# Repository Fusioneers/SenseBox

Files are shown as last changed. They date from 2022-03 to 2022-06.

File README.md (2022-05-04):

# Facharbeit

# Tool um gpx anzusehen
https://www.j-berkemeier.de/ShowGPX.html

## Fragestellung
_Kann man anhand von Umgebungsdaten mithilfe einer KI vorhersagen, auf welcher Höhe man sich befindet?
Falls ja, sind diese Vorhersagen genauer als herkömmliche Methoden?_

## Ansatz
Zunächst planen und bauen wir eine Sensorbox, welche diverse Umgebungswerte messen und speichern soll.

Die Sensorbox lassen wir in die Höhe steigen und messen dabei mit einem Seil die tatsächliche Höhe der Box.
Die aufgezeichneten Daten nutzen wir, um eine künstliche Intelligenz durch maschinelles Lernen zu trainieren.

Anschließend wird die Genauigkeit evaluiert und mit denen herkömmlicher Methoden zur Höhenmessung verglichen.

## Anforderungen
### Bauteile
* Microcontroller: Arduino nano / duo
* Sensoren
  * Kombo-Sensor für Luftdruck, Luftfeuchtigkeit & Temperatur
  * Anemometer (Sensor für Windgeschwindigkeit)
* Widerstände
* Kondensatoren
* SD-Karten-Lesegerät
* SD-Karte
* Speichermedium
* Steckbrett
* Steckbrückenkabel (2,54mm)
* LED
* Taster
* Akku
* PLA / Styropor / Schrauben etc.

### Bibliotheken

---
**Fusioneers** ([@Fusioneers](https://github.com/Fusioneers)) 2022

* **Kevin Kretz** ([@theKevinKretz](https://github.com/theKevinKretz))
* **Daniel Meiborg** ([@DanielMeiborg](https://github.com/DanielMeiborg))
* **Paul Maier** ([@C0mput3r5c13nt15t](https://github.com/C0mput3r5c13nt15t))
* **Lukas Pottgiesser** ([@Lukas-Pottgiesser](https://github.com/Lukas-Pottgiesser))

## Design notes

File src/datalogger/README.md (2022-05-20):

# Datalogger

## Besonderheiten bei den Variablen

Das Programm verwendet Variablen, die zur Kompellierung aufgelöst werden. Diese sind vor dem Setup-Teil mit
`#variable wert` gekennzeichent. Der Vorteil dieser Variablen besteht, darin, dass sie keinen Speicherplatz verbrauchen
und es trotzdem ermöglichen das Programm variabel und einfach modifizierbar zu gestallten.

Neben den Variablen findet sich auch folgende Kondition, die auch während der Kompillierung aufgelöst wird. Ist
ECHO_TO_SERIAL auf false gesetzt, wird der eingeschlossene Programmteil also einfach ignoriert und benötigt damit
weder Speicher noch Rechenleistung

~~~ c++
#if ECHO_TO_SERIAL
    ...
#endif //ECHO_TO_SERIAL
  
~~~

## Verwendung von interrupts

Das Programm verwendet einen interrupt für den Hallsensor, welcher im Setup-Teil definiert wird.

Mit der Zeile

~~~ c++
attachInterrupt(digitalPinToInterrupt(hallSensor), hallSensorTriggered, FALLING);
~~~

wird der Arduino darauf angewiesen, jedes mal, wenn der Wert am Port hallSensor von HIGH auf LOW fällt, die
Funktion hallSensorTriggered() aufzurufen, welche dann lastLallSesnorTriggerTime auf einen neuen Wert setzt, der
irgendwann im Loop-Teil engültig in die Log-Datei übertragen wird.

~~~ c++
// Diese Funktion wird immer aufgrufen, wenn die Ausgabe des Hall Sesnor von HIGH zu LOW wechselt (siehe setup)
void hallSensorTriggered() {
  // Falls das Programm am laufen ist
  if (_running) {
    // Setze die Zeit des letzten Aufrufs, auf die aktuelle Zeit
    lastLallSesnorTriggerTime = millis();
  }
}
~~~

Theoretisch ist es möglich, dass der Wert überschrieben wird, bevor er in die Log-Datei übertragen werden konnte. In
der Praxis ist dies allerdings sehr unwahrscheinlich, da dieser etwa 15 bis 20 mal pro Sekunde durchlaufen wird.

## Programmablauf

### Setup-Teil

Zunächst wird im Setup-Teil des Programmes alles initialisier, was im späteren Verlauf verwendet wird.
Darunter sind unter anderem die Log-Files, der BME, sowie weitere Sensoren und auch die LEDs. Hier wird
stets geprüft, ob der entsprechende Prozess erfolgreich verlief, ist dass der Fall, so wird am Ende des
Programmes gewartet, bis der An-/Ausknopf gedrückt wird. Gab es einen Fehler, so wird dieser über die Status LEDs
kommuniziert und zudem am seriellen Monitor ausgegeben.

~~~ c++
void setup(void)
{
  // Kontrolliert ob ein Fehler innerhalb des setup Teils aufgetreten ist
  bool errorOccuredInSetup = false;

  // Initialisiert den seriellen Monitor
  Serial.begin(9600);
  
  // Setzt den Pin-Mode der Status-LEDs auf OUTPUT
  pinMode(redLED, OUTPUT);
  pinMode(yellowLED, OUTPUT);
  pinMode(greenLED, OUTPUT);

  // Setzt den Pin-Mode des An- Ausschalters auf INPUT
  pinMode(onOffButton, INPUT);

  // Setzt den Pin-Mode des Hallsesnors auf INPUT
  pinMode(hallSensor, INPUT);
  
  // Attached die Funktion hallSensorTriggered, zu einem Ändern der Voltage am Port hallSensor von HIGH zu LOW
  attachInterrupt(digitalPinToInterrupt(hallSensor), hallSensorTriggered, FALLING);

  // Die gelbe LED wird für den restlichen Setup-Teil angeschaltet
  digitalWrite(yellowLED, HIGH); 

  Serial.println("Initializing SD card...");
  
  // Setzt den SD-Karten Pin vorsichtshalber bereits auf OUTPUT
  pinMode(10, OUTPUT);

  // Falls die SD-Karte nicht initialisiert werden kann, wird ein Fehler ausgegeben
  if (!SD.begin(chipSelect)) {
    error("Card failed, or not present"); // Ruft die error Methode auf, die sich dann um den Fehler kümmert
    errorOccuredInSetup = true; // Setzt errorOccuredInSetup auf wahr, sodass am Ende nicht in den loop Teil übergegangen wird
  }
  Serial.println("Card initialized.");

  // Erstellt ein neues Log-File mit dem Namen LOGGER + zweistellige noch nicht verwendete Zahl
  char filename[] = "LOGGER00.CSV";
  // Loopt duch alle möglichen Namen
  for (uint8_t i = 0; i < 100; i++) {
    filename[6] = i / 10 + '0';
    filename[7] = i % 10 + '0';
    if (! SD.exists(filename)) {
      // Falls der Name noch nicht belegt ist, wird das Log-File erstellt und der Loop unterbrochen
      logfile = SD.open(filename, FILE_WRITE);
      break;
    }
  }

  // Erstellt ein neues Log-File mit dem Namen HALLOG00 + zweistellige noch nicht verwendete Zahl
  char hall_trigger_filename[] = "HALLOG00.CSV";
  // Loopt duch alle möglichen Namen
  for (uint8_t i = 0; i < 100; i++) {
    hall_trigger_filename[6] = i / 10 + '0';
    hall_trigger_filename[7] = i % 10 + '0';
    if (! SD.exists(hall_trigger_filename)) {
      // Falls der Name noch nicht belegt ist, wird das Log-File erstellt und der Loop unterbrochen
      hall_trigger_logfile = SD.open(hall_trigger_filename, FILE_WRITE);
      break;
    }
  }

  // Falls eine der beiden Log-Dateien nicht erstellt wurde (weil z.B. alle Namen belegt waren), wird ein Fehler ausgegeben
  if (!logfile) {
    error("Could not create a logfile"); // Ruft die error Methode auf, die sich dann um den Fehler kümmert
    errorOccuredInSetup = true; // Setzt errorOccuredInSetup auf wahr, sodass am Ende nicht in den loop Teil übergegangen wird
  } else if (!hall_trigger_logfile) {
    error("Could not create a logfile for the hall sensor triggers"); // Ruft die error Methode auf, die sich dann um den Fehler kümmert
    errorOccuredInSetup = true; // Setzt errorOccuredInSetup auf wahr, sodass am Ende nicht in den loop Teil übergegangen wird
  } else {
    // Andernfalls werden die Namen der erstellten Log-Datein ausgegeben
    Serial.print("Logging to: ");
    Serial.print(filename);
    Serial.print(" and ");
    Serial.println(hall_trigger_filename);
  }

  // Falls keine Daten vom BME abgefragt werden können, wird ein Fehler ausgegeben
  if (!bme280.init()) {
    error("Could not read data from BME"); // Ruft die error Methode auf, die sich dann um den Fehler kümmert
    errorOccuredInSetup = true; // Setzt errorOccuredInSetup auf wahr, sodass am Ende nicht in den loop Teil übergegangen wird
  }

  // Setzt die Spaltennamen für die CSV-Log-Dateien
  logfile.println("timestamp,temperature,pressure,humidity,altitude,uv");
  hall_trigger_logfile.println("timestamp");
  // Gibt (falls ECHO_TO_SERIAL wahr ist) eine Warnung aus auf dem seriellen Monitor aus und setzt die Spaltennamen für die Ausgabe
  #if ECHO_TO_SERIAL
    Serial.println("Note: The timestamp starts with the execution of the programm and will overflow after approx. 50 days.");
    Serial.println("timestamp,temperature,pressure,humidity,altitude,uv"); 
  #endif //ECHO_TO_SERIAL

  delay(5000); // Wartet kurz

    // Falls noch keine Fehler aufgetreten ist, wird gewartet, bis der Start-Knopf gedrückt wird
  if (errorOccuredInSetup == false) {
    while (analogRead(onOffButton) < 1023) {
      delay(500);
    } 
  } else {
    // Andernfalls wird ein Fehler ausgegeben und in einen ewigen Loop übergegangen
    while (1==1) { 
      Serial.println("An error occured, see above");
      delay(900000); 
    }
  }

  // Schaltet die grüne LED an
  digitalWrite(greenLED, HIGH);

  delay(3000); // Wartet kurz

  // Die gelbe LED wird wieder ausgeschaltet
  digitalWrite(yellowLED, LOW);

  // Setzt _running auf wahr
  _running = true;
  
  // Die Startzeit wird gespeichert
  runningSince = millis();
}
~~~

### Loop-Teil

Im Loop-Teil angekommen, folgt der Ablauf dem Programmablaufplan (siehe nächster Punkt). Zunächst wird überprüft, ob
der An-/Ausknopf erneut gedrückt wurde und die Messung gegebenen Falls beendet, was wiederrum über die Status LEDs
kommuniziert wird. Ist dies nicht der Fall und _running ist wahr, so wird zuerst falls nicht 0 die Zeit des letzten
Auslösen des Hall-Sensors in die dafür vorgesehene Log-Datei geschrieben. Danach werden, sofern nicht ausschließlich der
Hall Sensor gemessen werden soll, die Daten der restlichen Sensoren erfasst und in die Log-Datei geschrieben bzw.
zusätzlich auch ausgegeben. Zum Schluss wird falls die letzte Synchronisierung auf die SD-Karte bereits eine bestimmte
Zeit her ist, diese wieder synchronisiert.

~~~ c++
void loop(void)
{  
  // Falls der An-/Aus-Knopf gedrückt wird, wird der Messvorgang beendet
  if (analogRead(onOffButton) >= 1023) {
    _running = false; // _running wird auf false gesetzt
    
    // Synchronisiert die gesammelten Daten, während die gelbe LED einmal blinkt
    digitalWrite(yellowLED, HIGH);
    logfile.flush();
    hall_trigger_logfile.flush();
    digitalWrite(yellowLED, LOW);
    
    digitalWrite(greenLED, LOW); // Schaltet die grüne LED aus
    digitalWrite(yellowLED, HIGH); // Schaltet die gelbe LED an
    digitalWrite(redLED, HIGH); // Schaltet die rote LED an
  }

  // Falls _running wahr ist, wird gemessen
  if (_running == true) {

    // Falls lastLallSesnorTriggerTime nicht 0 ist, wird lastLallSesnorTriggerTimein die Log-Datei geschrieben
    if (lastLallSesnorTriggerTime != 0) {

      // Gibt (falls ECHO_TO_SERIAL wahr ist) "Hall sensor triggered!" auf dem seriellen Monitor aus
      #if ECHO_TO_SERIAL
        Serial.println("Hall sensor triggered!");
      #endif //ECHO_TO_SERIAL

      // Schreibt lastLallSesnorTriggerTime in die Log-Datei
      hall_trigger_logfile.println(lastLallSesnorTriggerTime);

      // Setzt lastLallSesnorTriggerTime wieder auf 0
      lastLallSesnorTriggerTime = 0;
    }

    // Falls nicht nur der Hall Sensor gemessen werden soll, werden auch die Werte der anderen Sensoren gemessen
    if (!onlyMeasureHallSesnor) {

      // Setzt _timestamp auf die aktuelle Zeit minus der Startzeit
      unsigned long _timestamp = millis() - runningSince;
      
      // Schreibt _timestamp in die Log-Datei
      logfile.print(_timestamp);
      // Gibt (falls ECHO_TO_SERIAL wahr ist) _timestamp am seriellen Monitor aus
      #if ECHO_TO_SERIAL
        Serial.print(_timestamp);
      #endif //ECHO_TO_SERIAL
  
      // Liest die Sensorwerte des UV-Sensors aus und rechnet sie in den UVI um
      float analogSignal = analogRead(UVSensor);
      float voltage = analogSignal/1023*5;
      float uvIndex = voltage / 0.1;
  
      // Schreibt die Sesnorwerte in die Log-Datei
      logfile.print(", ");
      logfile.print(bme280.getTemperature());
      logfile.print(", ");
      logfile.print(bme280.getPressure());
      logfile.print(", ");
      logfile.print(bme280.getHumidity());
      logfile.print(", ");
      logfile.print(bme280.calcAltitude(bme280.getPressure()));
      logfile.print(", ");
      logfile.print(uvIndex);
      // Gibt (falls ECHO_TO_SERIAL wahr ist) die Sensorwerte am seriellen Monitor aus
      #if ECHO_TO_SERIAL
        Serial.print(", ");
        Serial.print(bme280.getTemperature());
        Serial.print(" °C");
        Serial.print(", ");
        Serial.print(bme280.getPressure());
        Serial.print(" Pascal");
        Serial.print(", ");
        Serial.print(bme280.getHumidity());
        Serial.print(", ");
        Serial.print(bme280.calcAltitude(bme280.getPressure()));
        Serial.print(" m");
        Serial.print(", ");
        Serial.print(uvIndex);
      #endif //ECHO_TO_SERIAL

      // Beginnt eine neue Zeile in der Log-Datei
      logfile.println();
      // Beginnt (falls ECHO_TO_SERIAL wahr ist) eine neue Zeile im Seriellen Monitor
      #if ECHO_TO_SERIAL
        Serial.println();
      #endif // ECHO_TO_SERIAL   
    }
  
    // Falls die letzte Synchronisierung länger als SYNC_INTERVAL Millisecunden her ist, wird die SD-Karte synchronisiert
    if ((millis() - syncTime) > SYNC_INTERVAL) {
      // Setzt syncTime auf die aktuelle Zeit
      syncTime = millis();
  
      // Die gesammelten Daten werden synchronisiert, während die gelbe LED einmal blinkt
      digitalWrite(yellowLED, HIGH);
      logfile.flush();
      hall_trigger_logfile.flush();
      digitalWrite(yellowLED, LOW);
    }
  }
}
~~~

### Programm Ablauf Plan (PAP)

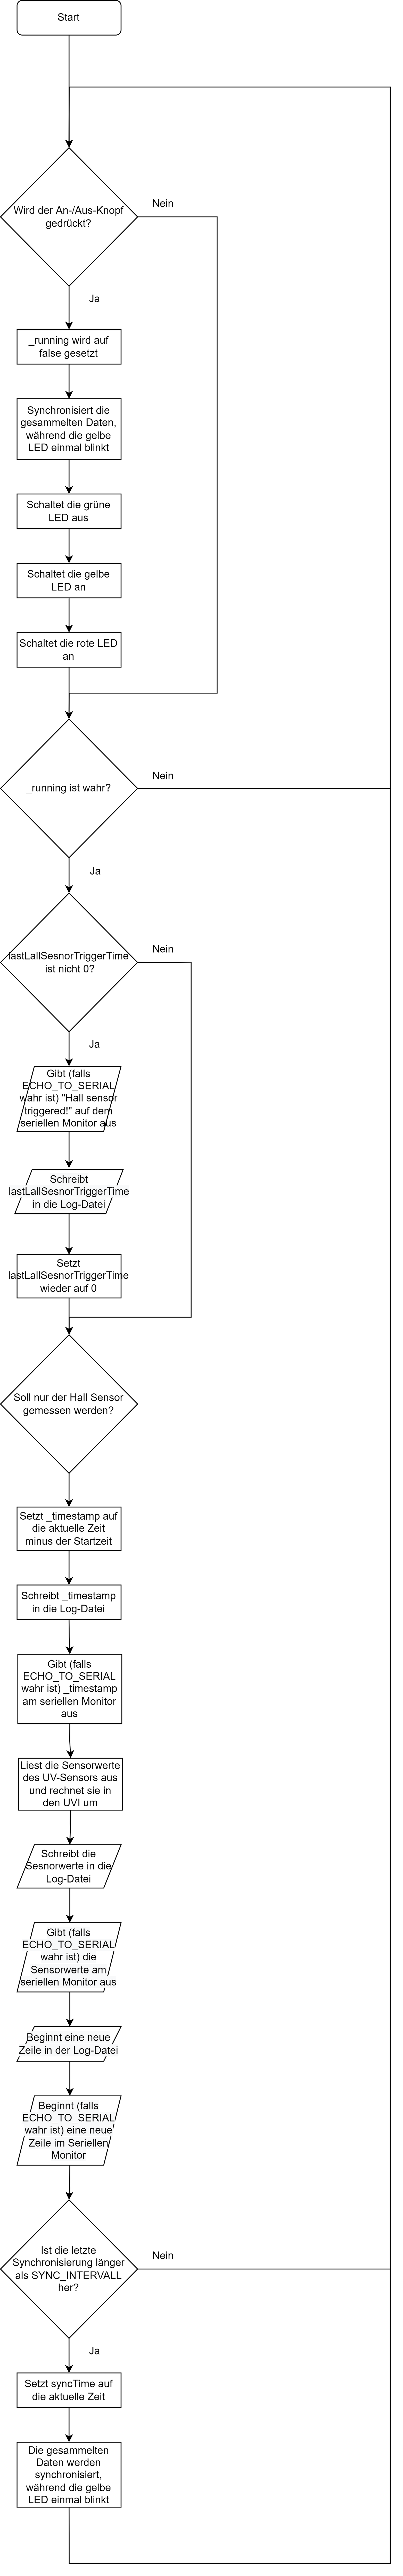
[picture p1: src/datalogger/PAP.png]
PAP


## Erklärung der Status LEDs

| grüne LED | gelbe LED | rote LED | Erklärung |
|---|---|---|---|
| ⚫ | 🟡 | ⚫ | Programm befindet sich noch im Setup-Teil |
| ⚫ | ⚫ | 🔴 | Programm schlug im Setup-Teil fehl (z.B. volle SD-Karte) |
| 🟢 | ✨ | ⚫ | Programm läuft fehlerfrei und schreibt die Daten auf die SD-Karte (Blinken bedeutet Synchronisierung) |
| ⚫ | 🟡 | 🔴 | Programm wurde erfolgreich beendet 

🟢, 🟡 und 🔴 bedeutet an  
⚫ bedeutet aus  
✨ bedeutet Blinken

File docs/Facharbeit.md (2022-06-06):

# Facharbeit

## Titelseite

## Inhaltsverzeichnis

## Aufgabenstellung und Zielsetzung

## Inhaltliche Grundlagen
### Funktionsprinzip Anemometer
Ein Anemometer ist ein Gerät zur Messung der Windgeschwindigkeit.
Es besteht aus einem drehbaren Aufsatz, der an einer senkrechten Achse befestigt ist.
An ihm sind Schalen angebracht, welche den Wind auffangen.
Je schneller die Windgeschwindigkeit, desto schneller drehen sich die Schalen oder Flügel.
Aus der Zahl der Umdrehungen pro Zeiteinheit wird schließlich die Windgeschwindigkeit berechnet.
Die Windgeschwindigkeit wird meist in der Einheit Meter pro Sekunde (m/s) gemessen.

### BME
Ein BME-Sensor ist ein Sensor, der Umgebungsparameter wie Temperatur, Feuchtigkeit und Druck misst.
Er kann mit einem Arduino verwendet werden, um diese Parameter zu messen.

### UV-Sensor

### 

## Ergebnisse

## Reflexion

## Literatur-/ Abbildungsverzeichnis

## Eigenständigkeitserklärung
Hiermit erkläre ich, dass ich die vorliegende Facharbeit „SenseBox“ selbstständig und ohne
fremde Hilfe angefertigt habe.
Ich habe dabei nur die in der Arbeit angegebenen Quellen und Hilfsmittel benutzt.

###

Kevin Kretz

## Laborbuch
siehe Anhänge

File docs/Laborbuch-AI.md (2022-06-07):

# Laborbuch AI

## Struktur

In Folgendem sind alle Models aufgeführt, die wir für die SenseBox AI getestet
und trainiert haben. Es wird zuerst die Architektur des Models, d.h. die
Kombination der Layer, aufgeführt. Dann folgt die durchschnittliche Abweichung
der vorhergesagten Höhen von den Testdaten, und anschließend eine Grafik,
in der das Model auf das Datenset 'Fahrt' angewandt wird.

## Model 0

### Model Architektur

```
Model: "sequential"
_________________________________________________________________
 Layer (type)                Output Shape              Param #   
=================================================================
 dense (Dense)               (None, 10)                50        
                                                                 
 dropout (Dropout)           (None, 10)                0         
                                                                 
 batch_normalization (BatchN  (None, 10)               40        
 ormalization)                                                   
                                                                 
 activation (Activation)     (None, 10)                0         
                                                                 
 dense_1 (Dense)             (None, 10)                110       
                                                                 
 dropout_1 (Dropout)         (None, 10)                0         
                                                                 
 batch_normalization_1 (Batc  (None, 10)               40        
 hNormalization)                                                 
                                                                 
 activation_1 (Activation)   (None, 10)                0         
                                                                 
 dense_2 (Dense)             (None, 10)                110       
                                                                 
 dropout_2 (Dropout)         (None, 10)                0         
                                                                 
 batch_normalization_2 (Batc  (None, 10)               40        
 hNormalization)                                                 
                                                                 
 activation_2 (Activation)   (None, 10)                0         
                                                                 
 dense_3 (Dense)             (None, 10)                110       
                                                                 
 dropout_3 (Dropout)         (None, 10)                0         
                                                                 
 batch_normalization_3 (Batc  (None, 10)               40        
 hNormalization)                                                 
                                                                 
 activation_3 (Activation)   (None, 10)                0         
                                                                 
 dense_4 (Dense)             (None, 1)                 11        
                                                                 
=================================================================
Total params: 551
Trainable params: 471
Non-trainable params: 80
_________________________________________________________________

```

### Durchschnittlicher absoluter Fehler auf Testdaten (in Meter)

24.566537857055664m

### Daten 2022-05-03-0004-VG mit Model ausgewertet

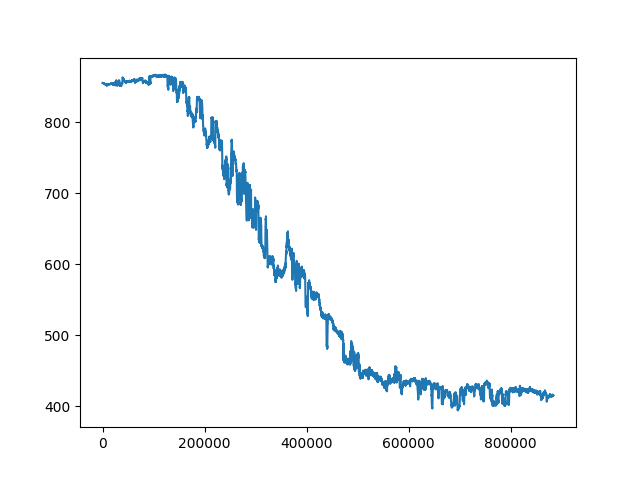
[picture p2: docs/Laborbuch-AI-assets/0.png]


## Model 1

### Model Architektur

```
Model: "sequential"
_________________________________________________________________
 Layer (type)                Output Shape              Param #   
=================================================================
 dense (Dense)               (None, 10)                50        
                                                                 
 dense_1 (Dense)             (None, 10)                110       
                                                                 
 dense_2 (Dense)             (None, 10)                110       
                                                                 
 dense_3 (Dense)             (None, 10)                110       
                                                                 
 dense_4 (Dense)             (None, 1)                 11        
                                                                 
=================================================================
Total params: 391
Trainable params: 391
Non-trainable params: 0
_________________________________________________________________

```

### Durchschnittlicher absoluter Fehler auf Testdaten (in Meter)

151.09603881835938m

### Daten 2022-05-03-0004-VG mit Model ausgewertet

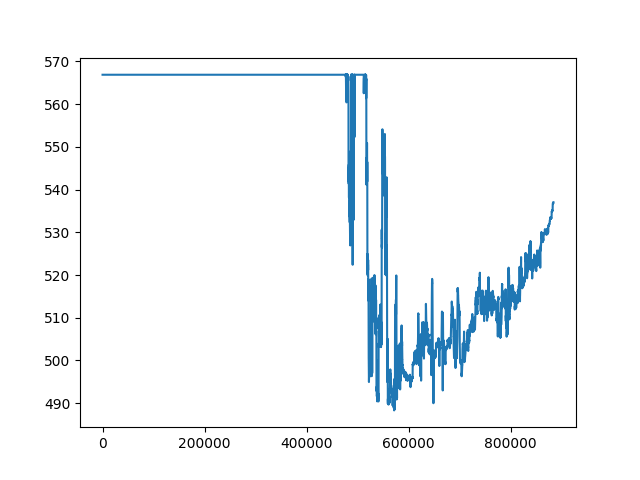
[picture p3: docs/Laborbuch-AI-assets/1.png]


## Model 2

### Model Architektur

```
Model: "sequential"
_________________________________________________________________
 Layer (type)                Output Shape              Param #   
=================================================================
 dense (Dense)               (None, 10)                50        
                                                                 
 dropout (Dropout)           (None, 10)                0         
                                                                 
 batch_normalization (BatchN  (None, 10)               40        
 ormalization)                                                   
                                                                 
 activation (Activation)     (None, 10)                0         
                                                                 
 dense_1 (Dense)             (None, 10)                110       
                                                                 
 dropout_1 (Dropout)         (None, 10)                0         
                                                                 
 batch_normalization_1 (Batc  (None, 10)               40        
 hNormalization)                                                 
                                                                 
 activation_1 (Activation)   (None, 10)                0         
                                                                 
 dense_2 (Dense)             (None, 10)                110       
                                                                 
 dropout_2 (Dropout)         (None, 10)                0         
                                                                 
 batch_normalization_2 (Batc  (None, 10)               40        
 hNormalization)                                                 
                                                                 
 activation_2 (Activation)   (None, 10)                0         
                                                                 
 dense_3 (Dense)             (None, 10)                110       
                                                                 
 dropout_3 (Dropout)         (None, 10)                0         
                                                                 
 batch_normalization_3 (Batc  (None, 10)               40        
 hNormalization)                                                 
                                                                 
 activation_3 (Activation)   (None, 10)                0         
                                                                 
 dense_4 (Dense)             (None, 1)                 11        
                                                                 
=================================================================
Total params: 551
Trainable params: 471
Non-trainable params: 80
_________________________________________________________________

```

### Durchschnittlicher absoluter Fehler auf Testdaten (in Meter)

50.0474739074707m

### Daten 2022-05-03-0004-VG mit Model ausgewertet

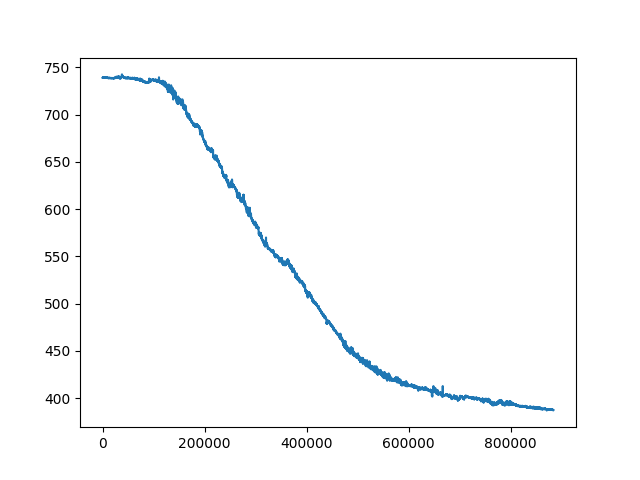
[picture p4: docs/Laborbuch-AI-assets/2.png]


## Model 3

### Model Architektur

```
Model: "sequential"
_________________________________________________________________
 Layer (type)                Output Shape              Param #   
=================================================================
 dense (Dense)               (None, 20)                100       
                                                                 
 dense_1 (Dense)             (None, 15)                315       
                                                                 
 dense_2 (Dense)             (None, 10)                160       
                                                                 
 dense_3 (Dense)             (None, 5)                 55        
                                                                 
 dense_4 (Dense)             (None, 1)                 6         
                                                                 
=================================================================
Total params: 636
Trainable params: 636
Non-trainable params: 0
_________________________________________________________________

```

### Durchschnittlicher absoluter Fehler auf Testdaten (in Meter)

7.441730976104736m

### Daten 2022-05-03-0004-VG mit Model ausgewertet

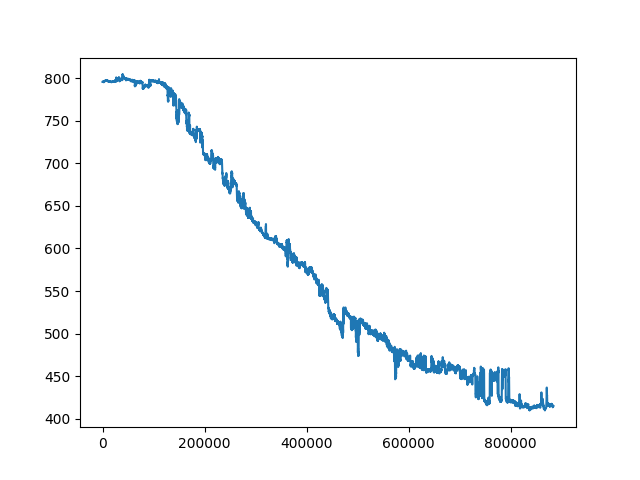
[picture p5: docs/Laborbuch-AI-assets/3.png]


## Model 4

### Model Architektur

```
Model: "sequential"
_________________________________________________________________
 Layer (type)                Output Shape              Param #   
=================================================================
 dense (Dense)               (None, 4)                 20        
                                                                 
 dense_1 (Dense)             (None, 4)                 20        
                                                                 
 dropout (Dropout)           (None, 4)                 0         
                                                                 
 dense_2 (Dense)             (None, 4)                 20        
                                                                 
 dense_3 (Dense)             (None, 1)                 5         
                                                                 
=================================================================
Total params: 65
Trainable params: 65
Non-trainable params: 0
_________________________________________________________________

```

### Durchschnittlicher absoluter Fehler auf Testdaten (in Meter)

52.309898376464844m

### Daten 2022-05-03-0004-VG mit Model ausgewertet

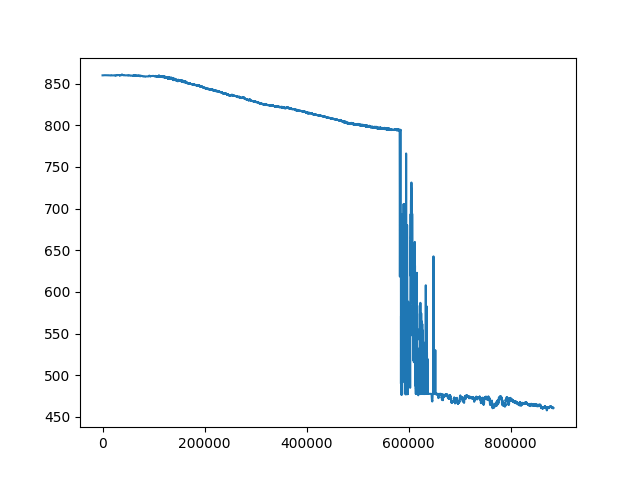
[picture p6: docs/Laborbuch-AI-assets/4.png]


## Model 5

### Model Architektur

```
Model: "sequential"
_________________________________________________________________
 Layer (type)                Output Shape              Param #   
=================================================================
 dense (Dense)               (None, 10)                50        
                                                                 
 dropout (Dropout)           (None, 10)                0         
                                                                 
 activation (Activation)     (None, 10)                0         
                                                                 
 dense_1 (Dense)             (None, 10)                110       
                                                                 
 dropout_1 (Dropout)         (None, 10)                0         
                                                                 
 activation_1 (Activation)   (None, 10)                0         
                                                                 
 dense_2 (Dense)             (None, 10)                110       
                                                                 
 dropout_2 (Dropout)         (None, 10)                0         
                                                                 
 activation_2 (Activation)   (None, 10)                0         
                                                                 
 dense_3 (Dense)             (None, 10)                110       
                                                                 
 dropout_3 (Dropout)         (None, 10)                0         
                                                                 
 activation_3 (Activation)   (None, 10)                0         
                                                                 
 dense_4 (Dense)             (None, 1)                 11        
                                                                 
=================================================================
Total params: 391
Trainable params: 391
Non-trainable params: 0
_________________________________________________________________

```

### Durchschnittlicher absoluter Fehler auf Testdaten (in Meter)

40.42742156982422m

### Daten 2022-05-03-0004-VG mit Model ausgewertet

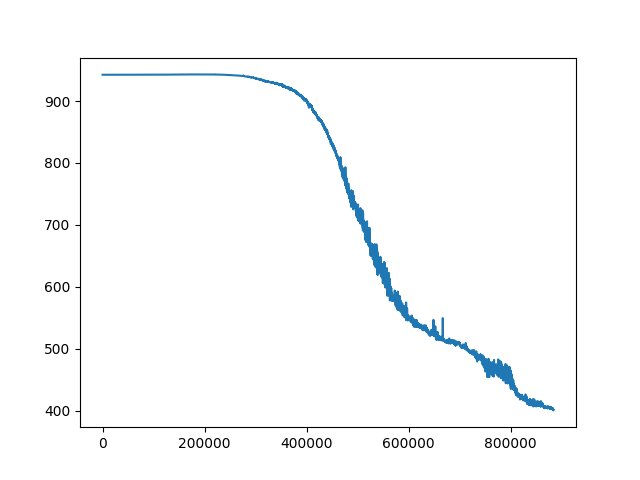
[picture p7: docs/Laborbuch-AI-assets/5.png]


## Model 6

### Model Architektur

```
Model: "sequential"
_________________________________________________________________
 Layer (type)                Output Shape              Param #   
=================================================================
 dense (Dense)               (None, 10)                50        
                                                                 
 dropout (Dropout)           (None, 10)                0         
                                                                 
 batch_normalization (BatchN  (None, 10)               40        
 ormalization)                                                   
                                                                 
 activation (Activation)     (None, 10)                0         
                                                                 
 dense_1 (Dense)             (None, 10)                110       
                                                                 
 dropout_1 (Dropout)         (None, 10)                0         
                                                                 
 batch_normalization_1 (Batc  (None, 10)               40        
 hNormalization)                                                 
                                                                 
 activation_1 (Activation)   (None, 10)                0         
                                                                 
 dense_2 (Dense)             (None, 10)                110       
                                                                 
 dropout_2 (Dropout)         (None, 10)                0         
                                                                 
 batch_normalization_2 (Batc  (None, 10)               40        
 hNormalization)                                                 
                                                                 
 activation_2 (Activation)   (None, 10)                0         
                                                                 
 dense_3 (Dense)             (None, 10)                110       
                                                                 
 dropout_3 (Dropout)         (None, 10)                0         
                                                                 
 batch_normalization_3 (Batc  (None, 10)               40        
 hNormalization)                                                 
                                                                 
 activation_3 (Activation)   (None, 10)                0         
                                                                 
 dense_4 (Dense)             (None, 1)                 11        
                                                                 
=================================================================
Total params: 551
Trainable params: 471
Non-trainable params: 80
_________________________________________________________________

```

### Durchschnittlicher absoluter Fehler auf Testdaten (in Meter)

29.35040855407715m

### Daten 2022-05-03-0004-VG mit Model ausgewertet

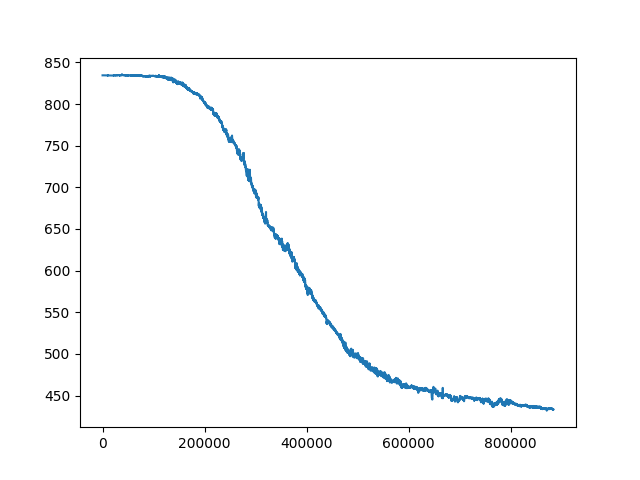
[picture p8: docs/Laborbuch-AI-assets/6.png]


## Model 7

### Model Architektur

```
Model: "sequential"
_________________________________________________________________
 Layer (type)                Output Shape              Param #   
=================================================================
 dense (Dense)               (None, 10)                50        
                                                                 
 dropout (Dropout)           (None, 10)                0         
                                                                 
 batch_normalization (BatchN  (None, 10)               40        
 ormalization)                                                   
                                                                 
 activation (Activation)     (None, 10)                0         
                                                                 
 dense_1 (Dense)             (None, 10)                110       
                                                                 
 dropout_1 (Dropout)         (None, 10)                0         
                                                                 
 batch_normalization_1 (Batc  (None, 10)               40        
 hNormalization)                                                 
                                                                 
 activation_1 (Activation)   (None, 10)                0         
                                                                 
 dense_2 (Dense)             (None, 10)                110       
                                                                 
 dropout_2 (Dropout)         (None, 10)                0         
                                                                 
 batch_normalization_2 (Batc  (None, 10)               40        
 hNormalization)                                                 
                                                                 
 activation_2 (Activation)   (None, 10)                0         
                                                                 
 dense_3 (Dense)             (None, 10)                110       
                                                                 
 dropout_3 (Dropout)         (None, 10)                0         
                                                                 
 batch_normalization_3 (Batc  (None, 10)               40        
 hNormalization)                                                 
                                                                 
 activation_3 (Activation)   (None, 10)                0         
                                                                 
 dense_4 (Dense)             (None, 1)                 11        
                                                                 
=================================================================
Total params: 551
Trainable params: 471
Non-trainable params: 80
_________________________________________________________________

```

### Durchschnittlicher absoluter Fehler auf Testdaten (in Meter)

84.46340942382812m

### Daten 2022-05-03-0004-VG mit Model ausgewertet

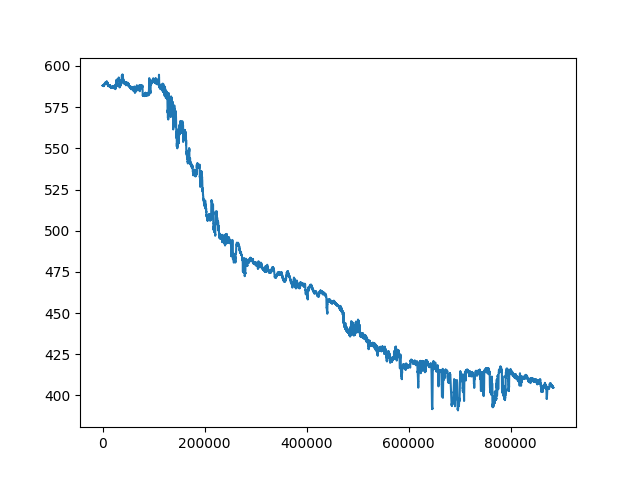
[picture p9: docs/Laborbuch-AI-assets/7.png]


## Model 8

### Model Architektur

```
Model: "sequential"
_________________________________________________________________
 Layer (type)                Output Shape              Param #   
=================================================================
 dense (Dense)               (None, 10)                50        
                                                                 
 dropout (Dropout)           (None, 10)                0         
                                                                 
 batch_normalization (BatchN  (None, 10)               40        
 ormalization)                                                   
                                                                 
 activation (Activation)     (None, 10)                0         
                                                                 
 dense_1 (Dense)             (None, 10)                110       
                                                                 
 dropout_1 (Dropout)         (None, 10)                0         
                                                                 
 batch_normalization_1 (Batc  (None, 10)               40        
 hNormalization)                                                 
                                                                 
 activation_1 (Activation)   (None, 10)                0         
                                                                 
 dense_2 (Dense)             (None, 10)                110       
                                                                 
 dropout_2 (Dropout)         (None, 10)                0         
                                                                 
 batch_normalization_2 (Batc  (None, 10)               40        
 hNormalization)                                                 
                                                                 
 activation_2 (Activation)   (None, 10)                0         
                                                                 
 dense_3 (Dense)             (None, 10)                110       
                                                                 
 dropout_3 (Dropout)         (None, 10)                0         
                                                                 
 batch_normalization_3 (Batc  (None, 10)               40        
 hNormalization)                                                 
                                                                 
 activation_3 (Activation)   (None, 10)                0         
                                                                 
 dense_4 (Dense)             (None, 1)                 11        
                                                                 
=================================================================
Total params: 551
Trainable params: 471
Non-trainable params: 80
_________________________________________________________________

```

### Durchschnittlicher absoluter Fehler auf Testdaten (in Meter)

23.120187759399414m

### Daten 2022-05-03-0004-VG mit Model ausgewertet

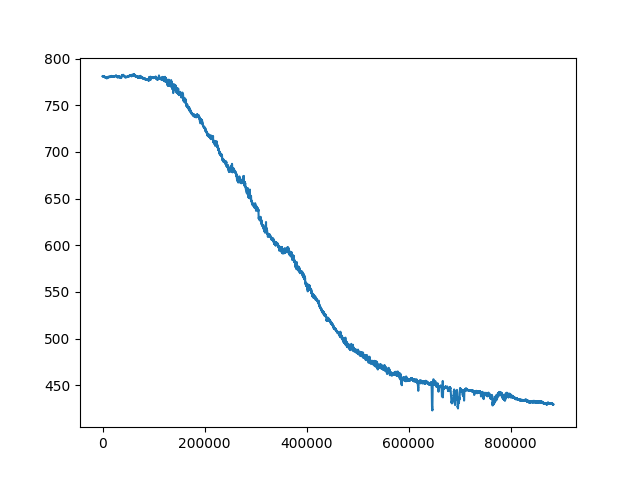
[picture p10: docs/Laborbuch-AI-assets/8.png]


## Model 9

### Model Architektur

```
Model: "sequential"
_________________________________________________________________
 Layer (type)                Output Shape              Param #   
=================================================================
 dense (Dense)               (None, 10)                50        
                                                                 
 dropout (Dropout)           (None, 10)                0         
                                                                 
 batch_normalization (BatchN  (None, 10)               40        
 ormalization)                                                   
                                                                 
 activation (Activation)     (None, 10)                0         
                                                                 
 dense_1 (Dense)             (None, 10)                110       
                                                                 
 dropout_1 (Dropout)         (None, 10)                0         
                                                                 
 batch_normalization_1 (Batc  (None, 10)               40        
 hNormalization)                                                 
                                                                 
 activation_1 (Activation)   (None, 10)                0         
                                                                 
 dense_2 (Dense)             (None, 10)                110       
                                                                 
 dropout_2 (Dropout)         (None, 10)                0         
                                                                 
 batch_normalization_2 (Batc  (None, 10)               40        
 hNormalization)                                                 
                                                                 
 activation_2 (Activation)   (None, 10)                0         
                                                                 
 dense_3 (Dense)             (None, 10)                110       
                                                                 
 dropout_3 (Dropout)         (None, 10)                0         
                                                                 
 batch_normalization_3 (Batc  (None, 10)               40        
 hNormalization)                                                 
                                                                 
 activation_3 (Activation)   (None, 10)                0         
                                                                 
 dense_4 (Dense)             (None, 1)                 11        
                                                                 
=================================================================
Total params: 551
Trainable params: 471
Non-trainable params: 80
_________________________________________________________________

```

### Durchschnittlicher absoluter Fehler auf Testdaten (in Meter)

35.41854476928711m

### Daten 2022-05-03-0004-VG mit Model ausgewertet

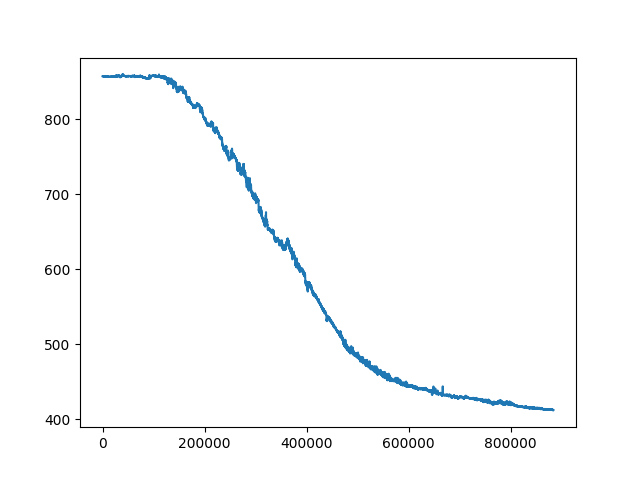
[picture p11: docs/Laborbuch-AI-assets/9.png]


## Model 10

### Model Architektur

```
Model: "sequential"
_________________________________________________________________
 Layer (type)                Output Shape              Param #   
=================================================================
 dense (Dense)               (None, 10)                50        
                                                                 
 dropout (Dropout)           (None, 10)                0         
                                                                 
 activation (Activation)     (None, 10)                0         
                                                                 
 dense_1 (Dense)             (None, 10)                110       
                                                                 
 dropout_1 (Dropout)         (None, 10)                0         
                                                                 
 activation_1 (Activation)   (None, 10)                0         
                                                                 
 dense_2 (Dense)             (None, 10)                110       
                                                                 
 dropout_2 (Dropout)         (None, 10)                0         
                                                                 
 activation_2 (Activation)   (None, 10)                0         
                                                                 
 dense_3 (Dense)             (None, 10)                110       
                                                                 
 dropout_3 (Dropout)         (None, 10)                0         
                                                                 
 activation_3 (Activation)   (None, 10)                0         
                                                                 
 dense_4 (Dense)             (None, 1)                 11        
                                                                 
=================================================================
Total params: 391
Trainable params: 391
Non-trainable params: 0
_________________________________________________________________

```

### Durchschnittlicher absoluter Fehler auf Testdaten (in Meter)

28.894609451293945m

### Daten 2022-05-03-0004-VG mit Model ausgewertet

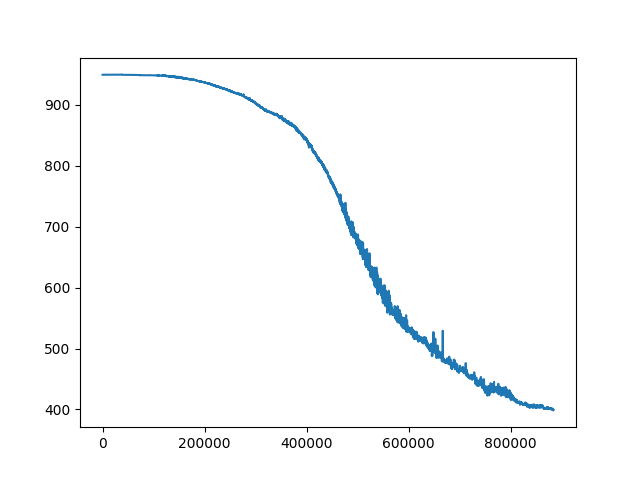
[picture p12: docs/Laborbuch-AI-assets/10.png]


## Model 11

### Model Architektur

```
Model: "sequential"
_________________________________________________________________
 Layer (type)                Output Shape              Param #   
=================================================================
 dense (Dense)               (None, 10)                50        
                                                                 
 dropout (Dropout)           (None, 10)                0         
                                                                 
 batch_normalization (BatchN  (None, 10)               40        
 ormalization)                                                   
                                                                 
 activation (Activation)     (None, 10)                0         
                                                                 
 dense_1 (Dense)             (None, 10)                110       
                                                                 
 dropout_1 (Dropout)         (None, 10)                0         
                                                                 
 batch_normalization_1 (Batc  (None, 10)               40        
 hNormalization)                                                 
                                                                 
 activation_1 (Activation)   (None, 10)                0         
                                                                 
 dense_2 (Dense)             (None, 10)                110       
                                                                 
 dropout_2 (Dropout)         (None, 10)                0         
                                                                 
 batch_normalization_2 (Batc  (None, 10)               40        
 hNormalization)                                                 
                                                                 
 activation_2 (Activation)   (None, 10)                0         
                                                                 
 dense_3 (Dense)             (None, 10)                110       
                                                                 
 dropout_3 (Dropout)         (None, 10)                0         
                                                                 
 batch_normalization_3 (Batc  (None, 10)               40        
 hNormalization)                                                 
                                                                 
 activation_3 (Activation)   (None, 10)                0         
                                                                 
 dense_4 (Dense)             (None, 1)                 11        
                                                                 
=================================================================
Total params: 551
Trainable params: 471
Non-trainable params: 80
_________________________________________________________________

```

### Durchschnittlicher absoluter Fehler auf Testdaten (in Meter)

33.355709075927734m

### Daten 2022-05-03-0004-VG mit Model ausgewertet

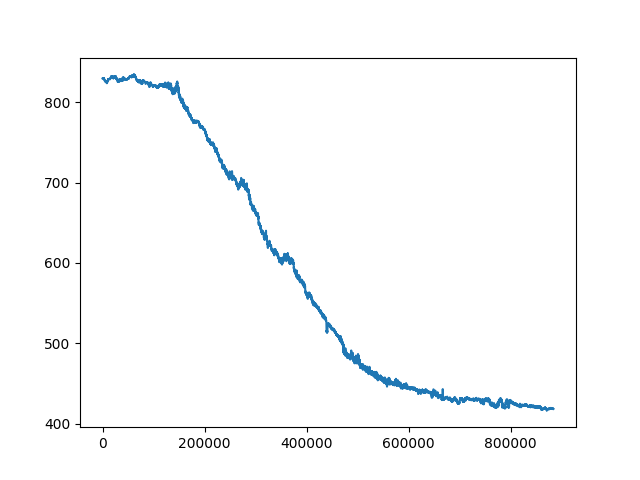
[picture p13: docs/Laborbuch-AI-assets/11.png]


## Model 12

### Model Architektur

```
Model: "sequential"
_________________________________________________________________
 Layer (type)                Output Shape              Param #   
=================================================================
 dense (Dense)               (None, 10)                50        
                                                                 
 dense_1 (Dense)             (None, 10)                110       
                                                                 
 dense_2 (Dense)             (None, 10)                110       
                                                                 
 dense_3 (Dense)             (None, 10)                110       
                                                                 
 dense_4 (Dense)             (None, 1)                 11        
                                                                 
=================================================================
Total params: 391
Trainable params: 391
Non-trainable params: 0
_________________________________________________________________

```

### Durchschnittlicher absoluter Fehler auf Testdaten (in Meter)

131.80239868164062m

### Daten 2022-05-03-0004-VG mit Model ausgewertet

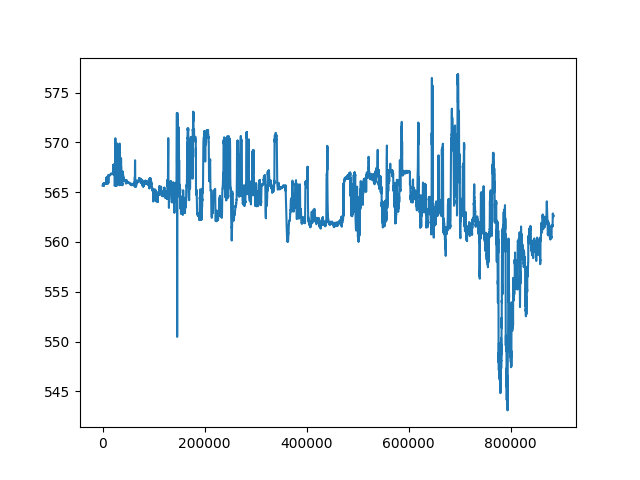
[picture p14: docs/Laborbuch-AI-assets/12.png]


## Model 13

### Model Architektur

```
Model: "sequential"
_________________________________________________________________
 Layer (type)                Output Shape              Param #   
=================================================================
 dense (Dense)               (None, 10)                50        
                                                                 
 dropout (Dropout)           (None, 10)                0         
                                                                 
 batch_normalization (BatchN  (None, 10)               40        
 ormalization)                                                   
                                                                 
 activation (Activation)     (None, 10)                0         
                                                                 
 dense_1 (Dense)             (None, 10)                110       
                                                                 
 dropout_1 (Dropout)         (None, 10)                0         
                                                                 
 batch_normalization_1 (Batc  (None, 10)               40        
 hNormalization)                                                 
                                                                 
 activation_1 (Activation)   (None, 10)                0         
                                                                 
 dense_2 (Dense)             (None, 10)                110       
                                                                 
 dropout_2 (Dropout)         (None, 10)                0         
                                                                 
 batch_normalization_2 (Batc  (None, 10)               40        
 hNormalization)                                                 
                                                                 
 activation_2 (Activation)   (None, 10)                0         
                                                                 
 dense_3 (Dense)             (None, 10)                110       
                                                                 
 dropout_3 (Dropout)         (None, 10)                0         
                                                                 
 batch_normalization_3 (Batc  (None, 10)               40        
 hNormalization)                                                 
                                                                 
 activation_3 (Activation)   (None, 10)                0         
                                                                 
 dense_4 (Dense)             (None, 1)                 11        
                                                                 
=================================================================
Total params: 551
Trainable params: 471
Non-trainable params: 80
_________________________________________________________________

```

### Durchschnittlicher absoluter Fehler auf Testdaten (in Meter)

57.701053619384766m

### Daten 2022-05-03-0004-VG mit Model ausgewertet

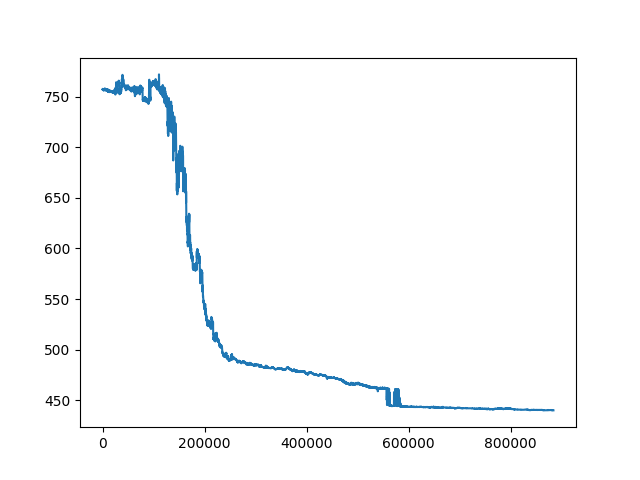
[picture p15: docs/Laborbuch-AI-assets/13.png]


## Model 14

### Model Architektur

```
Model: "sequential"
_________________________________________________________________
 Layer (type)                Output Shape              Param #   
=================================================================
 dense (Dense)               (None, 10)                50        
                                                                 
 dense_1 (Dense)             (None, 10)                110       
                                                                 
 dense_2 (Dense)             (None, 10)                110       
                                                                 
 dense_3 (Dense)             (None, 10)                110       
                                                                 
 dense_4 (Dense)             (None, 1)                 11        
                                                                 
=================================================================
Total params: 391
Trainable params: 391
Non-trainable params: 0
_________________________________________________________________

```

### Durchschnittlicher absoluter Fehler auf Testdaten (in Meter)

4.113324165344238m

### Daten 2022-05-03-0004-VG mit Model ausgewertet

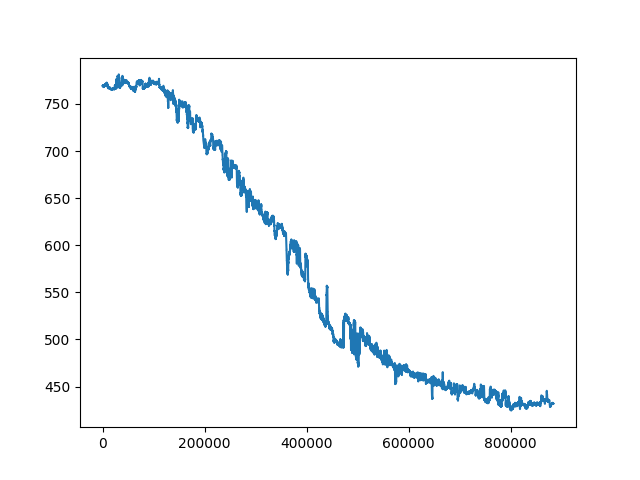
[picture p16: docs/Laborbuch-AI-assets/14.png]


## Model 15

### Model Architektur

```
Model: "sequential"
_________________________________________________________________
 Layer (type)                Output Shape              Param #   
=================================================================
 dense (Dense)               (None, 1)                 5         
                                                                 
=================================================================
Total params: 5
Trainable params: 5
Non-trainable params: 0
_________________________________________________________________

```

### Durchschnittlicher absoluter Fehler auf Testdaten (in Meter)

194.7505645751953m

### Daten 2022-05-03-0004-VG mit Model ausgewertet

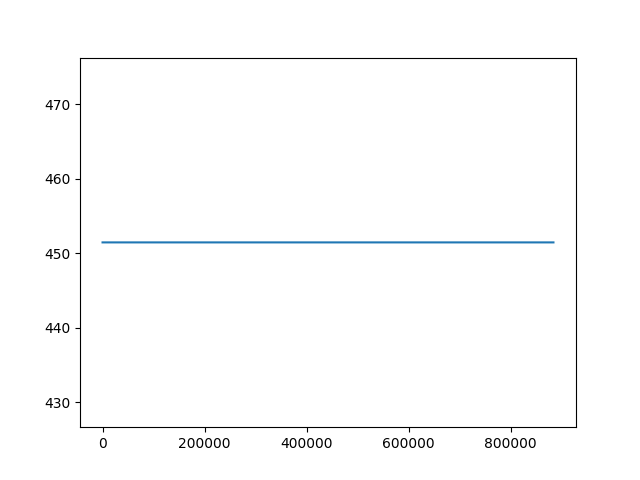
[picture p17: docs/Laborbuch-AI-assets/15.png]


## Model 16

### Model Architektur

```
Model: "sequential"
_________________________________________________________________
 Layer (type)                Output Shape              Param #   
=================================================================
 dense (Dense)               (None, 10)                50        
                                                                 
 dropout (Dropout)           (None, 10)                0         
                                                                 
 batch_normalization (BatchN  (None, 10)               40        
 ormalization)                                                   
                                                                 
 activation (Activation)     (None, 10)                0         
                                                                 
 dense_1 (Dense)             (None, 10)                110       
                                                                 
 dropout_1 (Dropout)         (None, 10)                0         
                                                                 
 batch_normalization_1 (Batc  (None, 10)               40        
 hNormalization)                                                 
                                                                 
 activation_1 (Activation)   (None, 10)                0         
                                                                 
 dense_2 (Dense)             (None, 10)                110       
                                                                 
 dropout_2 (Dropout)         (None, 10)                0         
                                                                 
 batch_normalization_2 (Batc  (None, 10)               40        
 hNormalization)                                                 
                                                                 
 activation_2 (Activation)   (None, 10)                0         
                                                                 
 dense_3 (Dense)             (None, 10)                110       
                                                                 
 dropout_3 (Dropout)         (None, 10)                0         
                                                                 
 batch_normalization_3 (Batc  (None, 10)               40        
 hNormalization)                                                 
                                                                 
 activation_3 (Activation)   (None, 10)                0         
                                                                 
 dense_4 (Dense)             (None, 1)                 11        
                                                                 
=================================================================
Total params: 551
Trainable params: 471
Non-trainable params: 80
_________________________________________________________________

```

### Durchschnittlicher absoluter Fehler auf Testdaten (in Meter)

46.39529037475586m

### Daten 2022-05-03-0004-VG mit Model ausgewertet

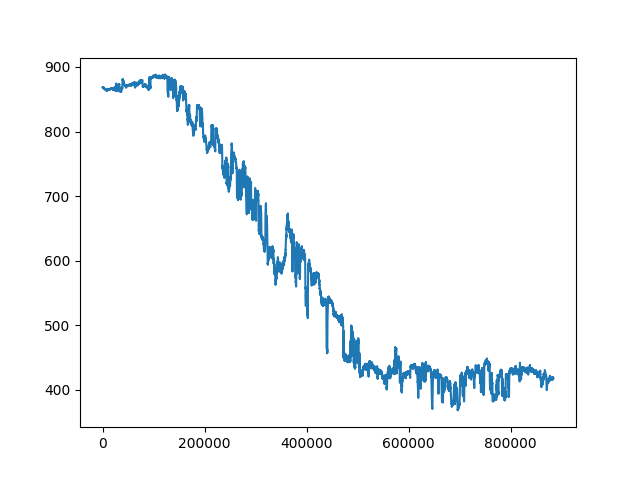
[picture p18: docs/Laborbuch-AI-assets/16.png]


## Model 17

### Model Architektur

```
Model: "sequential"
_________________________________________________________________
 Layer (type)                Output Shape              Param #   
=================================================================
 dense (Dense)               (None, 10)                50        
                                                                 
 dropout (Dropout)           (None, 10)                0         
                                                                 
 batch_normalization (BatchN  (None, 10)               40        
 ormalization)                                                   
                                                                 
 activation (Activation)     (None, 10)                0         
                                                                 
 dense_1 (Dense)             (None, 10)                110       
                                                                 
 dropout_1 (Dropout)         (None, 10)                0         
                                                                 
 batch_normalization_1 (Batc  (None, 10)               40        
 hNormalization)                                                 
                                                                 
 activation_1 (Activation)   (None, 10)                0         
                                                                 
 dense_2 (Dense)             (None, 10)                110       
                                                                 
 dropout_2 (Dropout)         (None, 10)                0         
                                                                 
 batch_normalization_2 (Batc  (None, 10)               40        
 hNormalization)                                                 
                                                                 
 activation_2 (Activation)   (None, 10)                0         
                                                                 
 dense_3 (Dense)             (None, 10)                110       
                                                                 
 dropout_3 (Dropout)         (None, 10)                0         
                                                                 
 batch_normalization_3 (Batc  (None, 10)               40        
 hNormalization)                                                 
                                                                 
 activation_3 (Activation)   (None, 10)                0         
                                                                 
 dense_4 (Dense)             (None, 1)                 11        
                                                                 
=================================================================
Total params: 551
Trainable params: 471
Non-trainable params: 80
_________________________________________________________________

```

### Durchschnittlicher absoluter Fehler auf Testdaten (in Meter)

30.151086807250977m

### Daten 2022-05-03-0004-VG mit Model ausgewertet

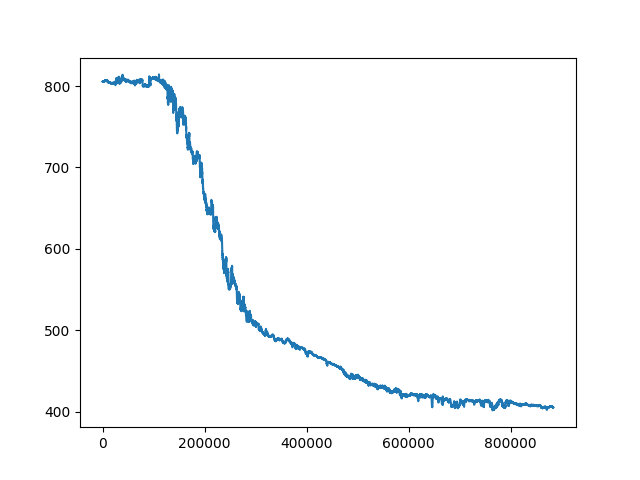
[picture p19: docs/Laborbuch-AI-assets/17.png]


## Model 18

### Model Architektur

```
Model: "sequential"
_________________________________________________________________
 Layer (type)                Output Shape              Param #   
=================================================================
 dense (Dense)               (None, 10)                50        
                                                                 
 dense_1 (Dense)             (None, 10)                110       
                                                                 
 dense_2 (Dense)             (None, 10)                110       
                                                                 
 dense_3 (Dense)             (None, 10)                110       
                                                                 
 dense_4 (Dense)             (None, 1)                 11        
                                                                 
=================================================================
Total params: 391
Trainable params: 391
Non-trainable params: 0
_________________________________________________________________

```

### Durchschnittlicher absoluter Fehler auf Testdaten (in Meter)

10.006917953491211m

### Daten 2022-05-03-0004-VG mit Model ausgewertet

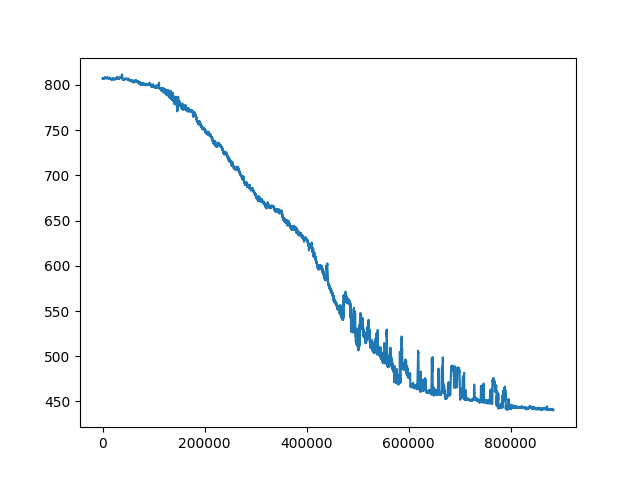
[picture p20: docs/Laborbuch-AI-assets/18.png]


## Model 19

### Model Architektur

```
Model: "sequential"
_________________________________________________________________
 Layer (type)                Output Shape              Param #   
=================================================================
 dense (Dense)               (None, 10)                50        
                                                                 
 dense_1 (Dense)             (None, 10)                110       
                                                                 
 dense_2 (Dense)             (None, 10)                110       
                                                                 
 dense_3 (Dense)             (None, 10)                110       
                                                                 
 dense_4 (Dense)             (None, 1)                 11        
                                                                 
=================================================================
Total params: 391
Trainable params: 391
Non-trainable params: 0
_________________________________________________________________

```

### Durchschnittlicher absoluter Fehler auf Testdaten (in Meter)

31.255023956298828m

### Daten 2022-05-03-0004-VG mit Model ausgewertet

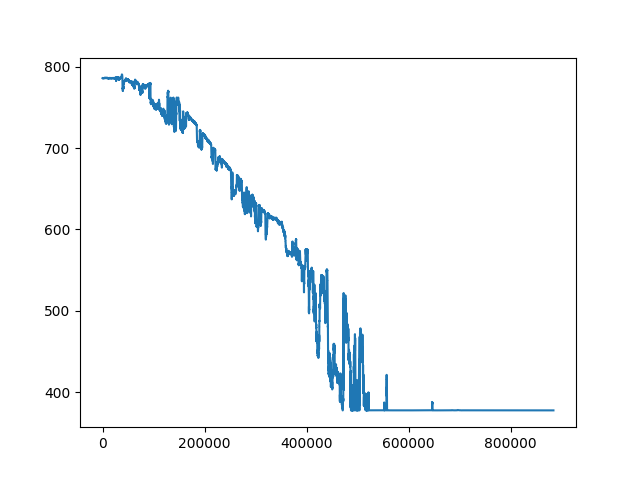
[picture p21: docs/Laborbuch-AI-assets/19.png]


## Model 20

### Model Architektur

```
Model: "sequential"
_________________________________________________________________
 Layer (type)                Output Shape              Param #   
=================================================================
 dense (Dense)               (None, 5)                 25        
                                                                 
 dense_1 (Dense)             (None, 5)                 30        
                                                                 
 dense_2 (Dense)             (None, 5)                 30        
                                                                 
 dense_3 (Dense)             (None, 5)                 30        
                                                                 
 dense_4 (Dense)             (None, 1)                 6         
                                                                 
=================================================================
Total params: 121
Trainable params: 121
Non-trainable params: 0
_________________________________________________________________

```

### Durchschnittlicher absoluter Fehler auf Testdaten (in Meter)

27.600261688232422m

### Daten 2022-05-03-0004-VG mit Model ausgewertet

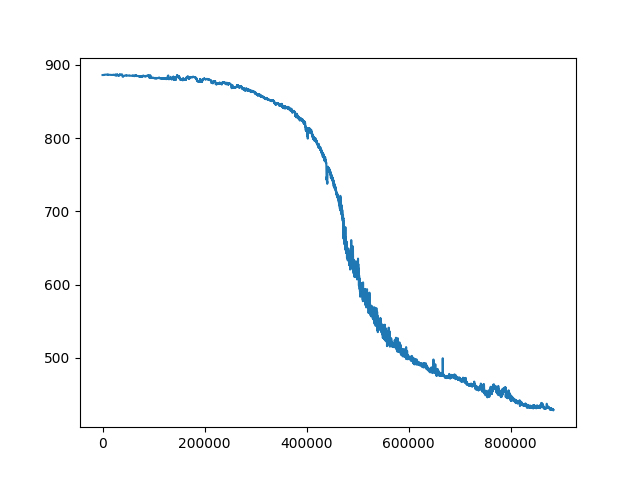
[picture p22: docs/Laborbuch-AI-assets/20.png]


## Model 21

### Model Architektur

```
Model: "sequential"
_________________________________________________________________
 Layer (type)                Output Shape              Param #   
=================================================================
 dense (Dense)               (None, 4)                 20        
                                                                 
 dense_1 (Dense)             (None, 4)                 20        
                                                                 
 dense_2 (Dense)             (None, 4)                 20        
                                                                 
 dense_3 (Dense)             (None, 4)                 20        
                                                                 
 dense_4 (Dense)             (None, 4)                 20        
                                                                 
 dense_5 (Dense)             (None, 1)                 5         
                                                                 
=================================================================
Total params: 105
Trainable params: 105
Non-trainable params: 0
_________________________________________________________________

```

### Durchschnittlicher absoluter Fehler auf Testdaten (in Meter)

17.21582794189453m

### Daten 2022-05-03-0004-VG mit Model ausgewertet

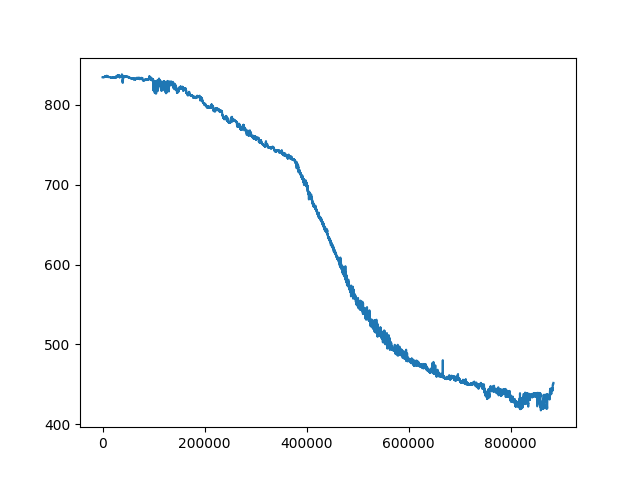
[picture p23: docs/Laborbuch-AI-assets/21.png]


## Model 22

### Model Architektur

```
Model: "sequential"
_________________________________________________________________
 Layer (type)                Output Shape              Param #   
=================================================================
 dense (Dense)               (None, 10)                50        
                                                                 
 dense_1 (Dense)             (None, 10)                110       
                                                                 
 dense_2 (Dense)             (None, 10)                110       
                                                                 
 dense_3 (Dense)             (None, 10)                110       
                                                                 
 dense_4 (Dense)             (None, 1)                 11        
                                                                 
=================================================================
Total params: 391
Trainable params: 391
Non-trainable params: 0
_________________________________________________________________

```

### Durchschnittlicher absoluter Fehler auf Testdaten (in Meter)

8.943251609802246m

### Daten 2022-05-03-0004-VG mit Model ausgewertet

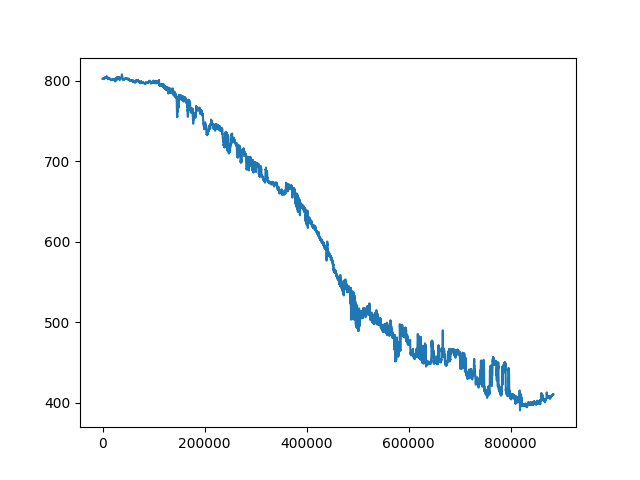
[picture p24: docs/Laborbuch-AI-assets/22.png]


## Model 23

### Model Architektur

```
Model: "sequential"
_________________________________________________________________
 Layer (type)                Output Shape              Param #   
=================================================================
 dense (Dense)               (None, 10)                50        
                                                                 
 dense_1 (Dense)             (None, 10)                110       
                                                                 
 dense_2 (Dense)             (None, 10)                110       
                                                                 
 dense_3 (Dense)             (None, 10)                110       
                                                                 
 dense_4 (Dense)             (None, 1)                 11        
                                                                 
=================================================================
Total params: 391
Trainable params: 391
Non-trainable params: 0
_________________________________________________________________

```

### Durchschnittlicher absoluter Fehler auf Testdaten (in Meter)

218.78134155273438m

### Daten 2022-05-03-0004-VG mit Model ausgewertet



## Model 24

### Model Architektur

```
Model: "sequential"
_________________________________________________________________
 Layer (type)                Output Shape              Param #   
=================================================================
 dense (Dense)               (None, 10)                50        
                                                                 
 dropout (Dropout)           (None, 10)                0         
                                                                 
 batch_normalization (BatchN  (None, 10)               40        
 ormalization)                                                   
                                                                 
 activation (Activation)     (None, 10)                0         
                                                                 
 dense_1 (Dense)             (None, 10)                110       
                                                                 
 dropout_1 (Dropout)         (None, 10)                0         
                                                                 
 batch_normalization_1 (Batc  (None, 10)               40        
 hNormalization)                                                 
                                                                 
 activation_1 (Activation)   (None, 10)                0         
                                                                 
 dense_2 (Dense)             (None, 10)                110       
                                                                 
 dropout_2 (Dropout)         (None, 10)                0         
                                                                 
 batch_normalization_2 (Batc  (None, 10)               40        
 hNormalization)                                                 
                                                                 
 activation_2 (Activation)   (None, 10)                0         
                                                                 
 dense_3 (Dense)             (None, 10)                110       
                                                                 
 dropout_3 (Dropout)         (None, 10)                0         
                                                                 
 batch_normalization_3 (Batc  (None, 10)               40        
 hNormalization)                                                 
                                                                 
 activation_3 (Activation)   (None, 10)                0         
                                                                 
 dense_4 (Dense)             (None, 1)                 11        
                                                                 
=================================================================
Total params: 551
Trainable params: 471
Non-trainable params: 80
_________________________________________________________________

```

### Durchschnittlicher absoluter Fehler auf Testdaten (in Meter)

33.779266357421875m

### Daten 2022-05-03-0004-VG mit Model ausgewertet



## Model 25

### Model Architektur

```
Model: "sequential"
_________________________________________________________________
 Layer (type)                Output Shape              Param #   
=================================================================
 dense (Dense)               (None, 10)                50        
                                                                 
 dense_1 (Dense)             (None, 10)                110       
                                                                 
 dense_2 (Dense)             (None, 10)                110       
                                                                 
 dense_3 (Dense)             (None, 10)                110       
                                                                 
 dense_4 (Dense)             (None, 10)                110       
                                                                 
 dense_5 (Dense)             (None, 10)                110       
                                                                 
 dense_6 (Dense)             (None, 1)                 11        
                                                                 
=================================================================
Total params: 611
Trainable params: 611
Non-trainable params: 0
_________________________________________________________________

```

### Durchschnittlicher absoluter Fehler auf Testdaten (in Meter)

9.034212112426758m

### Daten 2022-05-03-0004-VG mit Model ausgewertet



## Model 26

### Model Architektur

```
Model: "sequential"
_________________________________________________________________
 Layer (type)                Output Shape              Param #   
=================================================================
 dense (Dense)               (None, 10)                50        
                                                                 
 dropout (Dropout)           (None, 10)                0         
                                                                 
 batch_normalization (BatchN  (None, 10)               40        
 ormalization)                                                   
                                                                 
 activation (Activation)     (None, 10)                0         
                                                                 
 dense_1 (Dense)             (None, 10)                110       
                                                                 
 dropout_1 (Dropout)         (None, 10)                0         
                                                                 
 batch_normalization_1 (Batc  (None, 10)               40        
 hNormalization)                                                 
                                                                 
 activation_1 (Activation)   (None, 10)                0         
                                                                 
 dense_2 (Dense)             (None, 10)                110       
                                                                 
 dropout_2 (Dropout)         (None, 10)                0         
                                                                 
 batch_normalization_2 (Batc  (None, 10)               40        
 hNormalization)                                                 
                                                                 
 activation_2 (Activation)   (None, 10)                0         
                                                                 
 dense_3 (Dense)             (None, 10)                110       
                                                                 
 dropout_3 (Dropout)         (None, 10)                0         
                                                                 
 batch_normalization_3 (Batc  (None, 10)               40        
 hNormalization)                                                 
                                                                 
 activation_3 (Activation)   (None, 10)                0         
                                                                 
 dense_4 (Dense)             (None, 1)                 11        
                                                                 
=================================================================
Total params: 551
Trainable params: 471
Non-trainable params: 80
_________________________________________________________________

```

### Durchschnittlicher absoluter Fehler auf Testdaten (in Meter)

41.790836334228516m

### Daten 2022-05-03-0004-VG mit Model ausgewertet



## Model 27

### Model Architektur

```
Model: "sequential"
_________________________________________________________________
 Layer (type)                Output Shape              Param #   
=================================================================
 dense (Dense)               (None, 30)                150       
                                                                 
 dense_1 (Dense)             (None, 30)                930       
                                                                 
 dense_2 (Dense)             (None, 30)                930       
                                                                 
 dense_3 (Dense)             (None, 1)                 31        
                                                                 
=================================================================
Total params: 2,041
Trainable params: 2,041
Non-trainable params: 0
_________________________________________________________________

```

### Durchschnittlicher absoluter Fehler auf Testdaten (in Meter)

6.168951034545898m

### Daten 2022-05-03-0004-VG mit Model ausgewertet



## Model 28

### Model Architektur

```
Model: "sequential"
_________________________________________________________________
 Layer (type)                Output Shape              Param #   
=================================================================
 dense (Dense)               (None, 10)                50        
                                                                 
 dense_1 (Dense)             (None, 10)                110       
                                                                 
 dense_2 (Dense)             (None, 10)                110       
                                                                 
 dense_3 (Dense)             (None, 10)                110       
                                                                 
 dense_4 (Dense)             (None, 1)                 11        
                                                                 
=================================================================
Total params: 391
Trainable params: 391
Non-trainable params: 0
_________________________________________________________________

```

### Durchschnittlicher absoluter Fehler auf Testdaten (in Meter)

11.27298641204834m

### Daten 2022-05-03-0004-VG mit Model ausgewertet



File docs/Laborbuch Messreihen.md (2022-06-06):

# Laborbuch Messreihen

## SenseBox Testlauf, 01.05.2022

| Beschreibung | Wert |
|---|---|
| Höhe | 890m |
| Ort | Feuertreppe Saalbau ganz oben |
| Mit Strom verbunden | 2022-05-01 13:20 |
| Valide Daten ab | 2022-05-01 13:25 |
| Valide Daten bis | 2022-05-01 16:25 |
| Stopp | 2022-05-01 16:27 |
| Unique ID | 2022-05-01-0001-FT |

[Messreihe öffnen](../data/2022-05-01-0001-FT)

**Bemerkung:**
Beim Abholen hat nur noch die grüne LED geleuchtet und ist auch nicht ausgegangen, als der Knopf gedrückt wurde.

## Fahrradtour Vg, 03.05.2022

### Messung 1

| Beschreibung | Wert |
|---|---|
| Höhe | dynamisch |
| Unique ID | 2022-05-03-0001-VG |

[Messreihe öffnen](../data/2022-05-03-0001-VG)

### Messung 2

| Beschreibung | Wert |
|---|---|
| Höhe | dynamisch |
| Unique ID | 2022-05-03-0002-VG |

[Messreihe öffnen](../data/2022-05-03-0002-VG)

### Messung 3

| Beschreibung | Wert |
|---|---|
| Höhe | dynamisch |
| Unique ID | 2022-05-03-0003-VG |

[Messreihe öffnen](../data/2022-05-03-0003-VG)

### Messung 4

| Beschreibung | Wert |
|---|---|
| Höhe | dynamisch |
| Unique ID | 2022-05-03-0004-VG |

[Messreihe öffnen](../data/2022-05-03-0004-VG)

### Messung 5

| Beschreibung | Wert |
|---|---|
| Höhe | dynamisch |
| Unique ID | 2022-05-03-0005-VG |

[Messreihe öffnen](../data/2022-05-03-0005-VG)

## Freiburgfahrt A, 10.05.2022

### Himmelreich

| Beschreibung | Wert |
|---|---|
| Höhe | 445m |
| Start | 2022-05-10 15:05 |
| Temperatur | 24°C |
| Wolken | sehr leicht bewölkt |
| AQI | gut |
| UVI | 4 |
| Windgeschwindigkeit | 11 km/h |
| Windrichtung | Ost |
| Niederschlag | 0mm in den letzten 24h |
| Gefühlte Temperatur | 24°C |
| Luftfeuchtigkeit | 42% |
| Sicht | perfekt |
| Luftdruck | 1020 hPa |
| Luftdruck Tendenz | fallend |
| Ende | 2022-05-10 15:29 |
| ID | 00 |
| Unique ID | 2022-05-10-0001-HR |

[Messreihe öffnen](../data/2022-05-10-0001-HR)




### Freiburg-Littenweiler

| Beschreibung | Wert |
|---|---|
| Höhe | 318m |
| Start | 2022-05-10 15:43 |
| Temperatur | 26°C |
| Wolken | leicht bewölkt |
| AQI | moderat |
| UVI | 4 |
| Windgeschwindigkeit | 10 km/h |
| Windrichtung | Nord-Ost |
| Niederschlag | 0mm in den letzten 24h |
| Gefühlte Temperatur | 26°C |
| Luftfeuchtigkeit | 36% |
| Sicht | perfekt |
| Luftdruck | 1020 hPa |
| Luftdruck Tendenz | fallend |
| Ende | 2022-05-10 16:07 |
| ID | 02 |
| Unique ID | 2022-05-10-0002-LW |

[Messreihe öffnen](../data/2022-05-10-0002-LW)



### GPS-Kontrollpunkt

| Beschreibung | Wert |
|---|---|
| Höhe | 240m |
| Start | 2022-05-10 16:38 |
| Temperatur | 27°C |
| Wolken | leicht bewölkt |
| AQI | gut |
| UVI | 1 |
| Windgeschwindigkeit | 13 km/h |
| Windrichtung | Nord-Ost |
| Niederschlag | 0mm in den letzten 24h |
| Gefühlte Temperatur | 27°C |
| Luftfeuchtigkeit | 34% |
| Sicht | perfekt |
| Luftdruck | 1019 hPa |
| Luftdruck Tendenz | fallend |
| Ende | 2022-05-10 16:53 |
| ID | 03 |
| Unique ID | 2022-05-10-0003-KP |

[Messreihe öffnen](../data/2022-05-10-0003-KP)



### Hinterzarten Bahnhof

| Beschreibung | Wert |
|---|---|
| Höhe | 885m |
| Start | 2022-05-10 17:46 |
| Temperatur | 19°C |
| Wolken | leicht bewölkt |
| AQI | gut |
| UVI | 1 |
| Windgeschwindigkeit | 11 km/h |
| Windrichtung | Ost |
| Niederschlag | 0mm in den letzten 24h |
| Gefühlte Temperatur | 19°C |
| Luftfeuchtigkeit | 43% |
| Sicht | perfekt |
| Luftdruck | 1019 hPa |
| Luftdruck Tendenz | fallend |
| Ende | 2022-05-10 18:05 |
| ID | 04 | 
| Unique ID | 2022-05-10-0004-HZ |

[Messreihe öffnen](../data/2022-05-10-0004-HZ)



## Freiburgfahrt B, 13.05.2022

### GPS-Kontrollpunkt

| Beschreibung | Wert |
|---|---|
| Höhe | 240m |
| Start | 2022-05-13 13:10 |
| Temperatur | 17°C |
| Wolken | bewölkt |
| AQI | mäßig |
| UVI | 3 |
| Windgeschwindigkeit | 10 km/h |
| Windrichtung | Süd-Ost |
| Niederschlag | 8mm in den letzten 24h |
| Gefühlte Temperatur | 17°C |
| Luftfeuchtigkeit | 79% |
| Sicht | perfekt |
| Luftdruck | 1022 hPa |
| Luftdruck Tendenz | steigend |
| Ende | 2022-05-13 13:29 |
| ID | 02 |
| Unique ID | 2022-05-13-0001-KP |

[Messreihe öffnen](../data/2022-05-13-0001-KP)

### Freiburg-Littenweiler

| Beschreibung | Wert |
|---|---|
| Höhe | 318m |
| Start | 2022-05-13 14:53 |
| Temperatur | 19°C |
| Wolken | leicht bewölkt |
| AQI | mäßig |
| UVI | 4 |
| Windgeschwindigkeit | 11 km/h |
| Windrichtung | Nord-Ost |
| Niederschlag | 9mm in den letzten 24h |
| Gefühlte Temperatur | 19°C |
| Luftfeuchtigkeit | 64% |
| Sicht | perfekt |
| Luftdruck | 1021 hPa |
| Luftdruck Tendenz | fallend |
| Ende | 2022-05-13 15:15 |
| ID | 03 |
| Unique ID | 2022-05-13-0002-LW |

[Messreihe öffnen](../data/2022-05-13-0002-LW)

### Himmelreich

| Beschreibung | Wert |
|---|---|
| Höhe | 445m |
| Start | 2022-05-13 15:37 |
| Temperatur | 20°C |
| Wolken | meist bewölkt |
| AQI | sehr gut |
| UVI | 4 |
| Windgeschwindigkeit | 10 km/h |
| Windrichtung | Ost |
| Niederschlag | 11mm in den letzten 24h |
| Gefühlte Temperatur | 20°C |
| Luftfeuchtigkeit | 66% |
| Sicht | perfekt |
| Luftdruck | 1021 hPa |
| Luftdruck Tendenz | fallend |
| Ende | 2022-05-13 15:50 |
| ID | 04 |
| Unique ID | 2022-05-13-0003-HR |

[Messreihe öffnen](../data/2022-05-13-0003-HR)

### Uni Hof

48.010147, 7.857332

| Beschreibung | Wert |
|---|---|
| Höhe | 261m |
| Start | 2022-05-13 16:47 |
| Temperatur | 16°C |
| Wolken | leicht bewölkt |
| AQI | mäßig |
| UVI | 2 |
| Windgeschwindigkeit | 10 km/h |
| Windrichtung | Süd-Ost |
| Niederschlag | 8mm in den letzten 24h |
| Gefühlte Temperatur | 17°C |
| Luftfeuchtigkeit | 74% |
| Sicht | perfekt |
| Luftdruck | 1025 hPa |
| Luftdruck Tendenz | steigend |
| Ende | 2022-05-13 16:59 |
| ID | 00 |
| Unique ID | 2022-05-13-0004-UF |

[Messreihe öffnen](../data/2022-05-13-0004-UF)




### Uni Garten

48.009786, 7.85733

| Beschreibung | Wert |
|---|---|
| Höhe | 216m |
| Start | 2022-05-13 17:02 |
| Temperatur | 16°C |
| Wolken | leicht bewölkt |
| AQI | mäßig |
| UVI | 2 |
| Windgeschwindigkeit | 10 km/h |
| Windrichtung | Süd-Ost |
| Niederschlag | 8mm in den letzten 24h |
| Gefühlte Temperatur | 17°C |
| Luftfeuchtigkeit | 74% |
| Sicht | perfekt |
| Luftdruck | 1025 hPa |
| Luftdruck Tendenz | steigend |
| Ende | 2022-05-13 17:47 |
| ID | 01 |
| Unique ID | 2022-05-13-0005-UF |

[Messreihe öffnen](../data/2022-05-13-0005-UF)



### Freiburg Hbf

| Beschreibung | Wert |
|---|---|
| Höhe | 268m |
| Start | 2022-05-13 19:05 |
| Temperatur | 16°C |
| Wolken | leicht bewölkt |
| AQI | mäßig |
| UVI | 2 |
| Windgeschwindigkeit | 10 km/h |
| Windrichtung | Süd-Ost |
| Niederschlag | 8mm in den letzten 24h |
| Gefühlte Temperatur | 17°C |
| Luftfeuchtigkeit | 74% |
| Sicht | perfekt |
| Luftdruck | 1025 hPa |
| Luftdruck Tendenz | steigend |
| Ende | 2022-05-13 19:07 |
| ID | 02 |
| Unique ID | 2022-05-13-0006-FB |

[Messreihe öffnen](../data/2022-05-13-0006-FB)

### Fahrt

| Beschreibung | Wert |
|---|---|
| Höhe | dynamisch |
| Start | 2022-05-13 19:10 |
| Ende | 2022-05-13 19:23 |
| ID | 03 |
| Unique ID | 2022-05-13-0007-DY |

[Messreihe öffnen](../data/2022-05-13-0007-DY)

### Kirchzarten (Schattenbedingungen!)

| Beschreibung | Wert |
|---|---|
| Höhe | 392m |
| Start | 2022-05-13 19:29 |
| Ende | 2022-05-13 ca. 19:40 |
| ID | 04 |
| Unique ID | 2022-05-13-0008-KZ |

[Messreihe öffnen](../data/2022-05-13-0008-KZ)

**Bemerkung:**
Akku leer geworden (Rekonstruktion zufolge um 19:34)

## Langer Lauf, 17.05.2022 - 18.05.2022

Position: Feuertreppe oben

### Lauf Nachmittag

| Beschreibung | Wert |
|---|---|
| Höhe | 890m |
| Start | 2022-05-17 14:00 |
| Temperatur | 19°C |
| Wolken | leicht bewölkt |
| AQI | moderat |
| UVI | 0 |
| Windgeschwindigkeit | 6 km/h |
| Windrichtung | Westen |
| Niederschlag | 0mm in den letzten 24h |
| Gefühlte Temperatur | 19°C |
| Luftfeuchtigkeit | 57% |
| Sicht | perfekt |
| Luftdruck | 1019 hPa |
| Luftdruck Tendenz | steigend |
| Ende | 2022-05-17 19:00 |
| ID | 02 |
| Unique ID | 2022-05-17-0001-FT |

[Messreihe öffnen](../data/2022-05-17-0001-FT)

**Bemerkung:**
vor 19:00 Blinken aufgehört



### Lauf Nacht

| Beschreibung | Wert |
|---|---|
| Höhe | 890m |
| Start | 2022-05-17 19:00 |
| Temperatur | 19°C |
| Wolken | leicht bewölkt |
| AQI | moderat |
| UVI | 0 |
| Windgeschwindigkeit | 6 km/h |
| Windrichtung | Westen |
| Niederschlag | 0mm in den letzten 24h |
| Gefühlte Temperatur | 19°C |
| Luftfeuchtigkeit | 57% |
| Sicht | perfekt |
| Luftdruck | 1019 hPa |
| Luftdruck Tendenz | steigend |
| Ende | 2022-05-18 ca. 03:30 |
| ID | 03 |
| Unique ID | 2022-05-17-0002-FT |

[Messreihe öffnen](../data/2022-05-17-0002-FT)

**Bemerkung:**
Rekonstruktion zufolge bis 03:27;
Dateien für Logger geteilt in 03A und 03B (wegen Limit von Dateigrößen auf GitHub).



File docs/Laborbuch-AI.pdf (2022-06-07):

## Laborbuch AI

## Struktur

In Folgendem sind alle Models aufgeführt, die wir für die SenseBox AI getestet und trainiert haben. Es wird zuerst die Architektur des Models, d.h. die Kombination der Layer, aufgeführt. Dann folgt die durchschnittliche Abweichung der vorhergesagten Höhen von den Testdaten, und anschließend eine Grafik, in der das Model auf das Datenset ‘Fahrt’ angewandt wird.

## Model 0

Model Architektur

Model: "sequential"
_________________________________________________________________
Layer (type) | Output Shape | Param #
=================================================================
dense (Dense) | (None, 10) | 50
dropout (Dropout) | (None, 10) | 0
batch_normalization (BatchN | (None, 10) | 40
ormalization)
activation (Activation) | (None, 10) | 0
dense_1 (Dense) | (None, 10) | 110
dropout_1 (Dropout) | (None, 10) | 0
batch_normalization_1 (Batc | (None, 10) | 40
hNormalization)
activation_1 (Activation) | (None, 10) | 0
dense_2 (Dense) | (None, 10) | 110
dropout_2 (Dropout) | (None, 10) | 0
batch_normalization_2 (Batc | (None, 10) | 40
hNormalization)
activation_2 (Activation) | (None, 10) | 0
dense_3 (Dense) | (None, 10) | 110

1

dropout_3 (Dropout) | (None, 10) | 0
batch_normalization_3 (Batc | (None, 10) | 40
hNormalization)
activation_3 (Activation) | (None, 10) | 0
dense_4 (Dense) | (None, 1) | 11

================================================================= Total params: 551
Trainable params: 471
Non-trainable params: 80
_________________________________________________________________

Durchschnittlicher absoluter Fehler auf Testdaten (in Meter)

24.566537857055664m

Daten 2022-05-03-0004-VG mit Model ausgewertet


Figure 1: 0.png

2

## Model 1

Model Architektur

Model: "sequential"
_________________________________________________________________
Layer (type) | Output Shape | Param #
=================================================================
dense (Dense) | (None, 10) | 50
dense_1 (Dense) | (None, 10) | 110
dense_2 (Dense) | (None, 10) | 110
dense_3 (Dense) | (None, 10) | 110
dense_4 (Dense) | (None, 1) | 11

================================================================= Total params: 391
Trainable params: 391
Non-trainable params: 0
_________________________________________________________________

Durchschnittlicher absoluter Fehler auf Testdaten (in Meter)

151.09603881835938m

Daten 2022-05-03-0004-VG mit Model ausgewertet

## Model 2

Model Architektur

Model: "sequential"
_________________________________________________________________
Layer (type) | Output Shape | Param #
=================================================================
dense (Dense) | (None, 10) | 50
dropout (Dropout) | (None, 10) | 0
batch_normalization (BatchN | (None, 10) | 40
ormalization)
activation (Activation) | (None, 10) | 0
dense_1 (Dense) | (None, 10) | 110

3


Figure 2: 1.png

4

dropout_1 (Dropout) | (None, 10) | 0
batch_normalization_1 (Batc | (None, 10) | 40
hNormalization)
activation_1 (Activation) | (None, 10) | 0
dense_2 (Dense) | (None, 10) | 110
dropout_2 (Dropout) | (None, 10) | 0
batch_normalization_2 (Batc | (None, 10) | 40
hNormalization)
activation_2 (Activation) | (None, 10) | 0
dense_3 (Dense) | (None, 10) | 110
dropout_3 (Dropout) | (None, 10) | 0
batch_normalization_3 (Batc | (None, 10) | 40
hNormalization)
activation_3 (Activation) | (None, 10) | 0
dense_4 (Dense) | (None, 1) | 11

================================================================= Total params: 551
Trainable params: 471
Non-trainable params: 80
_________________________________________________________________

Durchschnittlicher absoluter Fehler auf Testdaten (in Meter)

50.0474739074707m

Daten 2022-05-03-0004-VG mit Model ausgewertet

## Model 3

Model Architektur

Model: "sequential"
_________________________________________________________________
Layer (type) | Output Shape | Param #

5

Figure 3: 38.png

6

=================================================================
dense (Dense) | (None, 20) | 100
dense_1 (Dense) | (None, 15) | 315
dense_2 (Dense) | (None, 10) | 160
dense_3 (Dense) | (None, 5) | 55
dense_4 (Dense) | (None, 1) | 6

================================================================= Total params: 636
Trainable params: 636
Non-trainable params: 0
_________________________________________________________________

Durchschnittlicher absoluter Fehler auf Testdaten (in Meter)

7.441730976104736m

Daten 2022-05-03-0004-VG mit Model ausgewertet

## Model 4

Model Architektur

Model: "sequential"
_________________________________________________________________
Layer (type) | Output Shape | Param #
=================================================================
dense (Dense) | (None, 4) | 20
dense_1 (Dense) | (None, 4) | 20
dropout (Dropout) | (None, 4) | 0
dense_2 (Dense) | (None, 4) | 20
dense_3 (Dense) | (None, 1) | 5

================================================================= Total params: 65
Trainable params: 65
Non-trainable params: 0
_________________________________________________________________

7


Figure 4: 3.png

8

Durchschnittlicher absoluter Fehler auf Testdaten (in Meter)

52.309898376464844m

Daten 2022-05-03-0004-VG mit Model ausgewertet


Figure 5: 36.png

## Model 5

Model Architektur

Model: "sequential"
_________________________________________________________________
Layer (type) | Output Shape | Param #
=================================================================
dense (Dense) | (None, 10) | 50
dropout (Dropout) | (None, 10) | 0
activation (Activation) | (None, 10) | 0
dense_1 (Dense) | (None, 10) | 110

9

dropout_1 (Dropout) | (None, 10) | 0
activation_1 (Activation) | (None, 10) | 0
dense_2 (Dense) | (None, 10) | 110
dropout_2 (Dropout) | (None, 10) | 0
activation_2 (Activation) | (None, 10) | 0
dense_3 (Dense) | (None, 10) | 110
dropout_3 (Dropout) | (None, 10) | 0
activation_3 (Activation) | (None, 10) | 0
dense_4 (Dense) | (None, 1) | 11

================================================================= Total params: 391
Trainable params: 391
Non-trainable params: 0
_________________________________________________________________

Durchschnittlicher absoluter Fehler auf Testdaten (in Meter)

40.42742156982422m

Daten 2022-05-03-0004-VG mit Model ausgewertet

## Model 6

Model Architektur

Model: "sequential"
_________________________________________________________________
Layer (type) | Output Shape | Param #
=================================================================
dense (Dense) | (None, 10) | 50
dropout (Dropout) | (None, 10) | 0
batch_normalization (BatchN | (None, 10) | 40
ormalization)
activation (Activation) | (None, 10) | 0

10


Figure 6: 5.png

11

dense_1 (Dense) | (None, 10) | 110
dropout_1 (Dropout) | (None, 10) | 0
batch_normalization_1 (Batc | (None, 10) | 40
hNormalization)
activation_1 (Activation) | (None, 10) | 0
dense_2 (Dense) | (None, 10) | 110
dropout_2 (Dropout) | (None, 10) | 0
batch_normalization_2 (Batc | (None, 10) | 40
hNormalization)
activation_2 (Activation) | (None, 10) | 0
dense_3 (Dense) | (None, 10) | 110
dropout_3 (Dropout) | (None, 10) | 0
batch_normalization_3 (Batc | (None, 10) | 40
hNormalization)
activation_3 (Activation) | (None, 10) | 0
dense_4 (Dense) | (None, 1) | 11

================================================================= Total params: 551
Trainable params: 471
Non-trainable params: 80
_________________________________________________________________

Durchschnittlicher absoluter Fehler auf Testdaten (in Meter)

29.35040855407715m

Daten 2022-05-03-0004-VG mit Model ausgewertet

## Model 7

Model Architektur

Model: "sequential"
_________________________________________________________________

12


Figure 7: 6.png

13

Layer (type) | Output Shape | Param #
=================================================================
dense (Dense) | (None, 10) | 50
dropout (Dropout) | (None, 10) | 0
batch_normalization (BatchN | (None, 10) | 40
ormalization)
activation (Activation) | (None, 10) | 0
dense_1 (Dense) | (None, 10) | 110
dropout_1 (Dropout) | (None, 10) | 0
batch_normalization_1 (Batc | (None, 10) | 40
hNormalization)
activation_1 (Activation) | (None, 10) | 0
dense_2 (Dense) | (None, 10) | 110
dropout_2 (Dropout) | (None, 10) | 0
batch_normalization_2 (Batc | (None, 10) | 40
hNormalization)
activation_2 (Activation) | (None, 10) | 0
dense_3 (Dense) | (None, 10) | 110
dropout_3 (Dropout) | (None, 10) | 0
batch_normalization_3 (Batc | (None, 10) | 40
hNormalization)
activation_3 (Activation) | (None, 10) | 0
dense_4 (Dense) | (None, 1) | 11

================================================================= Total params: 551
Trainable params: 471
Non-trainable params: 80
_________________________________________________________________

14

Durchschnittlicher absoluter Fehler auf Testdaten (in Meter)

84.46340942382812m

Daten 2022-05-03-0004-VG mit Model ausgewertet


Figure 8: 7.png

## Model 8

Model Architektur

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

15

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

================================================================= Total params: 551
Trainable params: 471
Non-trainable params: 80
_________________________________________________________________

Durchschnittlicher absoluter Fehler auf Testdaten (in Meter)

23.120187759399414m

Daten 2022-05-03-0004-VG mit Model ausgewertet

## Model 9

Model Architektur

Model: "sequential"

16

Figure 9: 8.png

17

_________________________________________________________________
Layer (type) | Output Shape | Param #
=================================================================
dense (Dense) | (None, 10) | 50
dropout (Dropout) | (None, 10) | 0
batch_normalization (BatchN | (None, 10) | 40
ormalization)
activation (Activation) | (None, 10) | 0
dense_1 (Dense) | (None, 10) | 110
dropout_1 (Dropout) | (None, 10) | 0
batch_normalization_1 (Batc | (None, 10) | 40
hNormalization)
activation_1 (Activation) | (None, 10) | 0
dense_2 (Dense) | (None, 10) | 110
dropout_2 (Dropout) | (None, 10) | 0
batch_normalization_2 (Batc | (None, 10) | 40
hNormalization)
activation_2 (Activation) | (None, 10) | 0
dense_3 (Dense) | (None, 10) | 110
dropout_3 (Dropout) | (None, 10) | 0
batch_normalization_3 (Batc | (None, 10) | 40
hNormalization)
activation_3 (Activation) | (None, 10) | 0
dense_4 (Dense) | (None, 1) | 11

================================================================= Total params: 551
Trainable params: 471
Non-trainable params: 80
_________________________________________________________________

18

Durchschnittlicher absoluter Fehler auf Testdaten (in Meter)

35.41854476928711m

Daten 2022-05-03-0004-VG mit Model ausgewertet


Figure 10: 9.png

## Model 10

Model Architektur

Model: "sequential"
_________________________________________________________________
Layer (type) | Output Shape | Param #
=================================================================
dense (Dense) | (None, 10) | 50
dropout (Dropout) | (None, 10) | 0
activation (Activation) | (None, 10) | 0
dense_1 (Dense) | (None, 10) | 110

19

dropout_1 (Dropout) | (None, 10) | 0
activation_1 (Activation) | (None, 10) | 0
dense_2 (Dense) | (None, 10) | 110
dropout_2 (Dropout) | (None, 10) | 0
activation_2 (Activation) | (None, 10) | 0
dense_3 (Dense) | (None, 10) | 110
dropout_3 (Dropout) | (None, 10) | 0
activation_3 (Activation) | (None, 10) | 0
dense_4 (Dense) | (None, 1) | 11

================================================================= Total params: 391
Trainable params: 391
Non-trainable params: 0
_________________________________________________________________

Durchschnittlicher absoluter Fehler auf Testdaten (in Meter)

28.894609451293945m

Daten 2022-05-03-0004-VG mit Model ausgewertet

## Model 11

Model Architektur

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

20


Figure 11: 34.png

21

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

================================================================= Total params: 551
Trainable params: 471
Non-trainable params: 80
_________________________________________________________________

Durchschnittlicher absoluter Fehler auf Testdaten (in Meter)

33.355709075927734m

Daten 2022-05-03-0004-VG mit Model ausgewertet

## Model 12

Model Architektur

Model: "sequential"
_________________________________________________________________

22


Figure 12: 11.png

23

Layer (type) | Output Shape | Param #
=================================================================
dense (Dense) | (None, 10) | 50
dense_1 (Dense) | (None, 10) | 110
dense_2 (Dense) | (None, 10) | 110
dense_3 (Dense) | (None, 10) | 110
dense_4 (Dense) | (None, 1) | 11

================================================================= Total params: 391
Trainable params: 391
Non-trainable params: 0
_________________________________________________________________

Durchschnittlicher absoluter Fehler auf Testdaten (in Meter)

131.80239868164062m

Daten 2022-05-03-0004-VG mit Model ausgewertet

## Model 13

Model Architektur

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

24


Figure 13: 33.png

25

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

================================================================= Total params: 551
Trainable params: 471
Non-trainable params: 80
_________________________________________________________________

Durchschnittlicher absoluter Fehler auf Testdaten (in Meter)

57.701053619384766m

Daten 2022-05-03-0004-VG mit Model ausgewertet
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

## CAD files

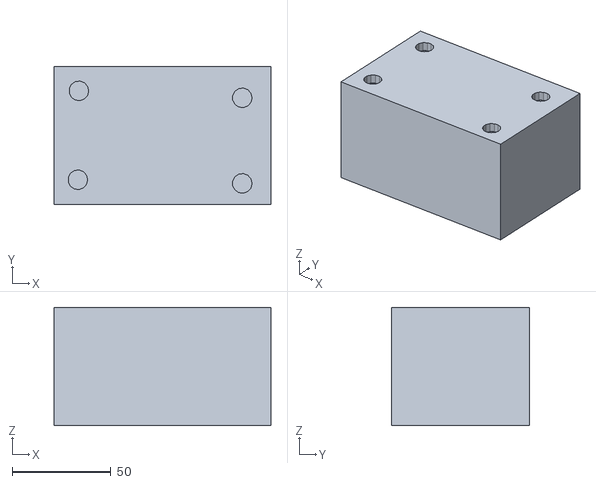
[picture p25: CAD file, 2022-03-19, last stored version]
docs/Skizze Facharbeit 3D Model.stl
110.0 x 70.0 x 60.0

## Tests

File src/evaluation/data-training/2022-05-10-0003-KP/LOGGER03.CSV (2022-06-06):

timestamp | temperature | pressure | humidity | altitude | uv
0 | 32.59 | 99156 | 28 | 182.14 | 3.23
16 | 32.59 | 99156 | 28 | 182.14 | 3.23
24 | 32.59 | 99156 | 28 | 182.14 | 3.23
32 | 32.59 | 99156 | 28 | 182.14 | 3.23
41 | 32.60 | 99160 | 28 | 181.80 | 3.23
49 | 32.60 | 99160 | 28 | 181.80 | 3.23
58 | 32.60 | 99160 | 28 | 181.80 | 3.23
67 | 32.60 | 99160 | 28 | 181.80 | 3.23
75 | 32.60 | 99160 | 28 | 181.80 | 3.23
83 | 32.60 | 99160 | 28 | 181.80 | 3.23
92 | 32.60 | 99160 | 28 | 181.80 | 3.23
101 | 32.60 | 99160 | 28 | 181.80 | 3.23
109 | 32.60 | 99160 | 28 | 181.80 | 3.23
124 | 32.60 | 99160 | 28 | 181.80 | 3.23
132 | 32.60 | 99160 | 28 | 182.14 | 3.23
141 | 32.58 | 99152 | 28 | 182.48 | 3.23
150 | 32.58 | 99152 | 28 | 182.48 | 3.23
158 | 32.58 | 99152 | 28 | 182.48 | 3.23
166 | 32.58 | 99152 | 28 | 182.48 | 3.23
174 | 32.58 | 99152 | 28 | 182.48 | 3.23
184 | 32.58 | 99152 | 28 | 182.48 | 3.23
192 | 32.58 | 99152 | 28 | 182.48 | 3.23
200 | 32.58 | 99152 | 28 | 182.48 | 3.23
209 | 32.58 | 99152 | 28 | 182.48 | 3.23
217 | 32.58 | 99152 | 28 | 182.48 | 3.23
226 | 32.58 | 99152 | 28 | 182.48 | 3.18
235 | 32.58 | 99155 | 28 | 182.22 | 3.23
247 | 32.58 | 99155 | 28 | 182.22 | 3.23
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

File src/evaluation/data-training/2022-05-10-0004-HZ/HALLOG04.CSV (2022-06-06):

timestamp
21737
198500
198516
198554
198578
253320
351011
352846
354621
356248
357487
358962
892932

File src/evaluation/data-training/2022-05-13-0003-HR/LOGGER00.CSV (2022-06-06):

timestamp | temperature | pressure | humidity | altitude | uv
0 | 26.64 | 96922 | 47 | 373.14 | 1.81
35 | 26.64 | 96922 | 47 | 373.14 | 1.81
46 | 26.64 | 96922 | 47 | 373.14 | 1.81
55 | 26.64 | 96922 | 47 | 373.14 | 1.81
63 | 26.64 | 96922 | 47 | 373.14 | 1.81
71 | 26.64 | 96922 | 47 | 373.14 | 1.81
80 | 26.64 | 96922 | 47 | 373.14 | 1.81
88 | 26.64 | 96922 | 47 | 373.14 | 1.81
96 | 26.64 | 96922 | 47 | 373.14 | 1.81
106 | 26.64 | 96922 | 47 | 373.14 | 1.81
114 | 26.64 | 96922 | 47 | 373.14 | 1.81
122 | 26.64 | 96922 | 47 | 373.14 | 1.81
131 | 26.64 | 96922 | 47 | 373.14 | 1.81
145 | 26.64 | 96922 | 47 | 373.14 | 1.81
153 | 26.64 | 96922 | 47 | 373.14 | 1.81
161 | 26.64 | 96922 | 47 | 373.14 | 1.81
170 | 26.64 | 96916 | 47 | 373.66 | 1.81
178 | 26.60 | 96916 | 47 | 373.66 | 1.81
187 | 26.60 | 96916 | 47 | 373.66 | 1.81
196 | 26.60 | 96916 | 47 | 373.66 | 1.81
204 | 26.60 | 96916 | 47 | 373.66 | 1.81
212 | 26.60 | 96916 | 47 | 373.66 | 1.81
221 | 26.60 | 96916 | 47 | 373.66 | 1.81
230 | 26.60 | 96916 | 47 | 373.66 | 1.81
238 | 26.60 | 96916 | 47 | 373.66 | 1.81
247 | 26.60 | 96916 | 47 | 373.66 | 1.81
255 | 26.60 | 96916 | 47 | 373.66 | 1.81
270 | 26.61 | 96915 | 47 | 373.74 | 1.81
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

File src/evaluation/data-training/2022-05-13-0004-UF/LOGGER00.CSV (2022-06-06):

timestamp | temperature | pressure | humidity | altitude | uv
0 | 24.76 | 99152 | 46 | 182.48 | 1.52
209 | 24.76 | 99152 | 46 | 182.48 | 1.52
219 | 24.76 | 99152 | 46 | 182.48 | 1.52
228 | 24.76 | 99152 | 46 | 182.48 | 1.52
236 | 24.76 | 99152 | 46 | 182.48 | 1.52
245 | 24.76 | 99152 | 46 | 182.48 | 1.52
254 | 24.76 | 99152 | 46 | 182.48 | 1.52
262 | 24.76 | 99152 | 46 | 182.48 | 1.52
270 | 24.76 | 99152 | 46 | 182.48 | 1.52
279 | 24.76 | 99152 | 46 | 182.48 | 1.52
288 | 24.76 | 99152 | 46 | 182.48 | 1.52
296 | 24.76 | 99152 | 46 | 182.48 | 1.52
305 | 24.76 | 99152 | 46 | 182.90 | 1.52
317 | 24.72 | 99147 | 46 | 182.90 | 1.52
327 | 24.72 | 99147 | 46 | 182.90 | 1.52
335 | 24.72 | 99147 | 46 | 182.90 | 1.52
343 | 24.72 | 99147 | 46 | 182.90 | 1.52
352 | 24.72 | 99147 | 46 | 182.90 | 1.52
360 | 24.72 | 99147 | 46 | 182.90 | 1.52
369 | 24.72 | 99147 | 46 | 182.90 | 1.52
378 | 24.72 | 99147 | 46 | 182.90 | 1.52
386 | 24.72 | 99147 | 46 | 182.90 | 1.52
394 | 24.72 | 99147 | 46 | 182.90 | 1.52
403 | 24.72 | 99147 | 46 | 182.82 | 1.52
412 | 24.72 | 99148 | 46 | 182.82 | 1.52
420 | 24.72 | 99148 | 46 | 182.82 | 1.52
429 | 24.72 | 99148 | 46 | 182.82 | 1.52
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

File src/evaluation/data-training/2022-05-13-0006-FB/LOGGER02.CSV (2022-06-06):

timestamp | temperature | pressure | humidity | altitude | uv
0 | 25.95 | 98975 | 43 | 197.48 | 0.73
35 | 25.95 | 98975 | 43 | 197.48 | 0.73
46 | 25.95 | 98975 | 43 | 197.48 | 0.73
54 | 25.95 | 98975 | 43 | 197.48 | 0.73
64 | 25.95 | 98975 | 43 | 197.48 | 0.73
72 | 25.95 | 98975 | 43 | 197.48 | 0.73
80 | 25.95 | 98975 | 43 | 197.48 | 0.73
88 | 25.95 | 98975 | 43 | 197.48 | 0.73
97 | 25.95 | 98975 | 43 | 197.48 | 0.73
106 | 25.95 | 98975 | 43 | 197.48 | 0.73
114 | 25.95 | 98975 | 43 | 197.48 | 0.73
123 | 25.95 | 98975 | 43 | 197.48 | 0.73
131 | 25.95 | 98975 | 43 | 197.48 | 0.73
144 | 25.91 | 98970 | 43 | 197.91 | 0.68
153 | 25.91 | 98970 | 43 | 197.91 | 0.73
161 | 25.91 | 98970 | 43 | 197.91 | 0.73
170 | 25.91 | 98970 | 43 | 197.91 | 0.73
178 | 25.91 | 98970 | 43 | 197.91 | 0.73
186 | 25.91 | 98970 | 43 | 197.91 | 0.73
196 | 25.91 | 98970 | 43 | 197.91 | 0.73
204 | 25.91 | 98970 | 43 | 197.91 | 0.73
212 | 25.91 | 98970 | 43 | 197.91 | 0.73
221 | 25.91 | 98970 | 43 | 197.91 | 0.73
229 | 25.91 | 98970 | 43 | 197.91 | 0.73
238 | 25.91 | 98969 | 44 | 197.99 | 0.73
247 | 25.90 | 98969 | 44 | 197.99 | 0.73
255 | 25.90 | 98969 | 44 | 197.99 | 0.73
269 | 25.90 | 98969 | 44 | 197.99 | 0.73
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

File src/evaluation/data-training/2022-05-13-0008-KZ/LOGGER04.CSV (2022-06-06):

timestamp | temperature | pressure | humidity | altitude | uv
0 | 23.04 | 97570 | 49 | 317.37 | 0.29
205 | 23.04 | 97570 | 49 | 317.29 | 0.29
217 | 23.04 | 97571 | 49 | 317.29 | 0.29
225 | 23.04 | 97571 | 49 | 317.29 | 0.29
233 | 23.04 | 97571 | 49 | 317.29 | 0.29
242 | 23.04 | 97571 | 49 | 317.29 | 0.29
250 | 23.04 | 97571 | 49 | 317.29 | 0.29
259 | 23.04 | 97571 | 49 | 317.29 | 0.29
268 | 23.04 | 97571 | 49 | 317.29 | 0.29
276 | 23.04 | 97571 | 49 | 317.29 | 0.29
284 | 23.04 | 97571 | 49 | 317.29 | 0.29
293 | 23.04 | 97571 | 49 | 317.29 | 0.29
302 | 23.04 | 97571 | 49 | 317.80 | 0.29
315 | 23.02 | 97565 | 49 | 317.80 | 0.24
323 | 23.02 | 97565 | 49 | 317.80 | 0.24
331 | 23.02 | 97565 | 49 | 317.80 | 0.24
341 | 23.02 | 97565 | 49 | 317.80 | 0.24
349 | 23.02 | 97565 | 49 | 317.80 | 0.24
357 | 23.02 | 97565 | 49 | 317.80 | 0.24
366 | 23.02 | 97565 | 49 | 317.80 | 0.24
374 | 23.02 | 97565 | 49 | 317.80 | 0.24
383 | 23.02 | 97565 | 49 | 317.80 | 0.24
392 | 23.02 | 97565 | 49 | 317.80 | 0.24
400 | 23.02 | 97565 | 49 | 317.72 | 0.24
408 | 23.02 | 97566 | 49 | 317.72 | 0.24
417 | 23.02 | 97566 | 49 | 317.72 | 0.24
426 | 23.02 | 97566 | 49 | 317.72 | 0.24
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

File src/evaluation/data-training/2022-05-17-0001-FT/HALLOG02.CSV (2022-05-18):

timestamp
291243
291997
292525
294051
294490
298582
298665
298695
298725
298763
298833
298847
298885
298902
298943
298967
298996
299013
299047
299874
299904
299926
299944
300005
300033
300057
300085
300124
300167
300183
300205
300264
300405
300442
300483
300643
300664
300753
300785
300805
301116
301135
301182
304418
304560
304606
304625
304660
304687
304705
304741
304756
304790
304817
304835
304865
304886
304907
304945
304966
304985
305449
305467
305506
305545
305575
305588
305709
306017
306025
306081
306097
306277
306308
306362
306390
306459
306487
306837
307025
307062
307089
307140
307185
307216
307325
307358
307389
307898
307915
307958
307978
308016
308125
308217
309167
309187
309452
309469
309487
309581
309968
309999
310150
310171
310199
310226
310389
310410
310448
310468
310518
310541
310571
310599
310618
310749
310769
310799
310820
310847
313541
313572
313589
313628
313651
313689
313713
314109
314133
314447
314483
314562
315123
315141
317693
318052
318072
318554
318573
331544
331585
332185
332216
332347
332378
332407
332436
332455
332505
332636
336248
336270
336287
336308
336535
336563
341172
341233
341263
341310
341331
341352
341470
341511
341541
341560
341629
341654
341771
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

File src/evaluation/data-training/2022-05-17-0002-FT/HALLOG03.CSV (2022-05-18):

timestamp
14519
33707
36305
36476
36965
37468
37491
37511
37645
37884
37905
38025
38079
38364
432701
572014
572160
7818719
7819693
7819731
7819753
7819772
7819810
7819833
7819851
12072224
12072766
13259022
13259044
13259934
13259954
13259975
13311469
13312011
13312038
13378819
13469762
13471474
13991317
13991342
13992436
17283177

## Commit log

2022-03-05 Arduino code commented
2022-03-09 On Off Button
2022-03-19 added sample data
    [LOGGER00.CSV, LOGGER01.CSV, LOGGER02.CSV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]
2022-03-23 improved data preparation
    [LOGGER00.CSV, LOGGER01.CSV, LOGGER02.CSV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]
2022-03-25 removed empty files
    [LOGGER42.CSV, LOGGER44.CSV, LOGGER45.CSV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]
2022-04-28 An-/Ausschalter umgestaltet und Startzeit relativ zum Drücken des Start-Knopfes
2022-04-29 Better comments + Interrupts for measuring wind speed
2022-05-01 Added exploratory_analysis.ipynb
    [HALLOG00.CSV, LOGGER00.CSV, LOGGER24.CSV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]
2022-05-01 Implemented test training session
    [HALLOG00.CSV, HALLOG01.CSV, HALLOG02.CSV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]
2022-05-04 Updated datalogger and new data and moved python files back into place
    [HALLOG01.CSV, HALLOG02.CSV, HALLOG03.CSV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]
2022-05-07 Pressure in Pascal and delay before waiting for button press
2022-05-10 Update to datalogger.ino and new data
    [HALLOG00.CSV, HALLOG02.CSV, HALLOG03.CSV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]
2022-05-13 New data and better documented datalogger.ino
    [HALLOG00.CSV, HALLOG01.CSV, HALLOG02.CSV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]
2022-05-16 added gpx extraction
    [LOGGER01.CSV]
2022-05-18 added Feuertreppe data
    [HALLOG02.CSV, HALLOG03.CSV]
2022-06-03 Add Laborbuch-AI-Fahrradtour
    [exact_pressure_2022-05-03-Fahrradtour_Vg_LOGGER04.CSV]
2022-06-06 updated Laborbuch Messreihen.md
    [HALLOG00.CSV, HALLOG01.CSV, HALLOG02.CSV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]
2022-06-06 added images and unified data
    [HALLOG00.CSV, HALLOG02.CSV, HALLOG03.CSV]
2022-06-07 Improve Laborbuch-AI
    [HALLOG00.CSV, HALLOG01.CSV, HALLOG02.CSV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]
2022-06-07 Add evaluation/data-training
    [2022-05-03-0004-VG-exact-pressure.CSV]
